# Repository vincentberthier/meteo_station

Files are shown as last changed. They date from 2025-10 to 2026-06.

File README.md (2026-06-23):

# meteo_station

Weather-station firmware in embedded Rust for the ESP32-H2 (ESP32-H2-DevKitM-1),
built on the [Embassy](https://embassy.dev) async runtime over esp-hal + esp-rtos
(`no_std`, `riscv32imac-unknown-none-elf`).

## Workspace layout

- `crates/meteo-firmware` — ESP32-H2 binary: esp-hal/esp-rtos init, GPIO8 status
  LED, Embassy tasks (BMP388 + MLX90614 + BME280 + VEML7700 on a shared I2C bus,
  aggregator, on-chip BLE, RWDT watchdog). esp deps are gated to
  `cfg(target_arch = "riscv32")`.
- `crates/meteo-lib` — hardware-agnostic drivers (host-testable) using
  `embedded-hal-async` traits: BMP388 barometer, MLX90614 IR thermometer, BME280
  humidity sensor, VEML7700 ambient light sensor, and the v2 BLE wire-frame
  (encode/decode + diagnostics byte).
- `crates/meteo-tui` — terminal dashboard (host, `x86_64-linux`): connects to the
  station over BLE, decodes telemetry frames, and renders a live ratatui UI
  (telemetry table + air-temp / sky-temp / pressure charts).

## Build & flash

```bash
just build     # release firmware (riscv32imac)
just flash      # flash to device (espflash, over native USB-Serial-JTAG)
just run        # flash + attach defmt monitor
just clippy     # firmware (riscv) + meteo-lib + meteo-tui (host), -D warnings
just test       # host unit tests (cargo nextest, meteo-lib + meteo-tui)
just format     # cargo fmt
```

See `CLAUDE.md` for the pin allocation, datasheets, and the espflash logging
procedure.

## Live dashboard

`just tui-run` launches the terminal dashboard. It connects to the `MeteoStation`
BLE peripheral and renders live telemetry in the terminal.

```bash
just tui-build                      # build only
just tui-run                        # connect to default address F0:CA:FE:00:00:01
just tui-run -- --address AA:BB:CC:DD:EE:FF   # override station address
```

Press `q`, Esc, or Ctrl-C to quit.

Host prerequisite: `bluetoothd` must be running at runtime; `libdbus-1-dev` is
required at build time (provides the BlueZ D-Bus binding).

## BLE acceptance — `scripts/ble_soak.sh` + `scripts/ble_notify_check.sh`

The ESP32-H2 advertises **on-chip** BLE as `MeteoStation` (static random address
`F0:CA:FE:00:00:01`) and pushes an 18-byte v2 telemetry frame at 1 Hz over a GATT
notify characteristic. The host unit tests only prove the frame codec; two scripts
(run on gaia, BlueZ 5.86) are the real acceptance gate for the radio link:

- **`ble_soak.sh`** — link-stability soak (described below).
- **`ble_notify_check.sh`** — data-flow check: subscribes via BlueZ `AcquireNotify`
  and asserts at least 5 well-formed 18-byte frames (byte[0] == `0x02`) within the
  window. It uses `AcquireNotify` rather than `bluetoothctl notify on` because BlueZ
  only re-emits the `Value` property when it _changes_, and the near-constant
  telemetry would otherwise be deduped to silence.

The script drives, indefinitely:

```
connect → hold HOLD_SECS → disconnect → wait GAP_SECS → reconnect → …
```

polling the link every second via the BlueZ D-Bus `Connected` property. It
prints one `PASS (held 360s)` line per cycle and exits **non-zero** on any
mid-window drop or failed reconnect. A single passing cycle is not acceptance —
the link must hold and repeat over a sustained run.

### Running it

It runs **on gaia** (BlueZ 5.86), which has `bluetoothctl`, `busctl`, and `doas`.
`doas` is needed because the script writes BlueZ connection parameters to
`debugfs` (these reset on every `systemctl restart bluetooth`, so they are
reapplied each run). Deploy and run:

```bash
scp scripts/ble_soak.sh gaia:
ssh gaia ./ble_soak.sh        # Ctrl-C to stop cleanly
```

The script **never starts a scan** — it connects by address off blueman's
standing discovery cache, avoiding a `Discovering: yes` adapter wedge. Ensure
the device is powered and advertising and that blueman discovery is running
before starting.

### Configuration (environment variables)

| Variable | Default | Meaning |
| --- | --- | --- |
| `DEVICE` | `F0:CA:FE:00:00:01` | BLE address of the peripheral |
| `ADAPTER` | `hci0` | Local HCI adapter |
| `HOLD_SECS` | `360` | Seconds the link must stay up per cycle (6 min) |
| `GAP_SECS` | `90` | Seconds between disconnect and reconnect |
| `CONNECT_TIMEOUT` | `30` | Per-step deadline (connect / cache appearance)  |
| `CONN_MIN` | `6` | debugfs `conn_min_interval` (×1.25 ms) |
| `CONN_MAX` | `12` | debugfs `conn_max_interval` (×1.25 ms) |
| `SUPERVISION` | `600` | debugfs `supervision_timeout` (×10 ms = 6 s) |

Example — a shorter hold while iterating:

```bash
HOLD_SECS=60 GAP_SECS=15 ssh gaia ./ble_soak.sh
```

If the link drops, diagnose with `btmon` on gaia during a hold before changing
firmware; the first tuning knobs are the connection-interval / supervision
values, not another code patch.

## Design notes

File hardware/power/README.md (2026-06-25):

# Power subsystem

Solar charging + power path for the weather station, captured as a KiCad 10 schematic.

## Chain

```
PV-12W ─▶ [U6 INA219] ─▶ CN3791 12V MPPT ─▶ 1S LiPo 10Ah ─▶ [U7 INA219] ─▶ MT3608 (5.0V) ─▶ D1 ─▶ DevKit 5V pin
            0x40           (CV term 4.2V)     (buffer + PCM)     0x41
            (harvest)                                            (load + Vbatt)
```

- **Panel:** Seeed PV-12W — Vmp 12 V, Voc 14 V, Isc ~1 A (matches the **12 V** CN3791 variant).
- **Charger:** Hailege CN3791 single-cell MPPT, terminates at 4.2 V. Panel's ~1 A is a
  gentle 0.1C into the 10 Ah cell.
- **Boost:** MT3608 module trimmed to **5.0 V**, feeding the DevKit `5V` pin (J1/14).
- **Isolation diode (D1, 1N5817):** the MT3608 5 V feeds the DevKit 5V pin through D1
  (~0.45 V drop, LDO still has headroom). When you flash over USB, VBUS appears on the 5V
  pin internally (~5 V) and wins; D1 blocks any back-feed into the boost. USB is the
  DevKit's own port, so no second diode is needed.
- **Current/power telemetry (2× INA219, I²C):** two INA219 breakouts (DEWOTHV / INA219B,
  on-board 0.1 Ω 1 % shunt, ±3.2 A) on the shared I2C0 bus, VCC on 3V3.
  - **U6 @ 0x40** — high-side on the PV feed (`SOLAR+ → SOLAR_CHG`): solar **harvest
    current** + panel voltage (bus input rated to 26 V, fine for the ~12–14 V panel).
  - **U7 @ 0x41** — high-side on the battery→boost feed (`VBAT → VLOAD`): **load current**
    drawn by the system + **battery voltage** (the INA219 bus register, more accurate than
    the SAR ADC). Addresses set by the A0 solder jumper.
- **Battery sense:** the GPIO2 / ADC1_CH1 divider is **gone** — battery voltage now comes
  from U7's bus reading. GPIO2 is freed as a spare ADC.
- **I²C pull-ups:** R3/R4 = 4.75 kΩ on SDA/SCL (now six devices on the bus).
- **Decoupling:** C1 (22 µF) at the MT3608 input on `VLOAD` (right at boost VIN, after the
  U7 shunt), C2/C3 (100 µF + 10 µF) on the 5 V rail, C4–C6 on 3V3 (10 µF bulk + 100 nF per
  sensor) — sized to ride out the BLE radio's TX current bursts.

All parts are on hand (see the project Mouser order); the two INA219 modules arrived
2026-06-21 (lot of 2). Current/power telemetry is now populated on the sheet.

## Files

| File | What |
| --- | --- |
| `meteo_power.kicad_sch` | The schematic (KiCad 10, ERC-clean). |
| `meteo_power.kicad_pro` | Project file. |
| `meteo_power.pdf` / `.svg` | Rendered exports. |
| `gen_power_sch.py` | Generator that produces the `.kicad_sch`. |

The schematic is **generated**, not hand-drawn: `gen_power_sch.py` reuses the system KiCad
symbol libraries and wires nets with on-sheet labels (no point-to-point routing). Edit the
`COMPS` / net map in the script and regenerate rather than editing the `.kicad_sch` by hand
— but the `.kicad_sch` is committed so it opens without regenerating.

## Regenerate

```bash
just power-sch        # regenerate sch + ERC + PDF/SVG
```

Needs `kicad-cli` and the KiCad symbol libraries under `/usr/share/kicad/symbols`. The
generator also takes an explicit output directory: `python3 gen_power_sch.py <outdir>`.

## Layout note

Modules (panel, CN3791, MT3608, DevKit, sensors) appear as connector symbols; only the
discretes (R/C/D) are real placed parts. This is a system-interconnect schematic, not a
board — there is no PCB. A soldered carrier board is a possible later step.

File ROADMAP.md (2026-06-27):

# Roadmap — future ideas

The firmware and the bench prototype are at a good **v1**. This file collects ideas
for a future **v2** (mostly mechanical / hardware enclosure work). Nothing here is
committed or scheduled — these are notes to revisit, not a backlog.

**Target deployment: outdoors at ~1500 m in the Alps.** Hard freezing, snow, rime ice,
and large day/night temperature swings are design drivers throughout — see
[Cold-climate operation](#cold-climate-operation-alps-1500-m).

## Enclosure & mechanical

### Proper box

Move off the bench into a real weatherproof enclosure. This is the umbrella task that
several items below feed into (sensor placement, waterproofing, PCB mounting).

### MLX90614 sky-IR protection

The MLX90614 must point straight up at the sky to detect clouds, so its FOV cannot be
shaded or covered in normal operation. But an upward-facing can collects rain and snow,
which then sits in front of the optics and ruins readings.

Options under consideration:

- **Flap** — simple, but a flat flap doesn't drain; water/snow pools on it.
- **Servo** — park the sensor (tilt/rotate away, or under a small shelter) when
  precipitation is detected, point back at zenith otherwise. Better drainage behaviour,
  but more mechanical design work to integrate cleanly into the box. Could trigger off
  the rain-gauge tip events that the firmware already counts.

No decision yet; the servo path is the leading idea but the box geometry has to support it.

### VEML7700 luminosity placement

The ambient-light sensor **cannot** sit inside the box or in shade — it needs an open
view of the sky to read luminosity. Mounting it on top exposes it to weather, so it
needs its own small waterproof (étanche) window/dome. Placement and sealing are an open
design question and interact with the box and the MLX mount.

### Air-temperature radiation shield

The air-temp sensors (BMP388 / BME280) must read true ambient air, not a sun-baked box.
Direct sun on the enclosure will bias the temperature high by several °C and also throws
off the MLX90614 ambient reference. A louvered radiation shield (Stevenson-screen style)
with airflow around the sensor is the standard fix, and it interacts with where the box,
the VEML window, and the MLX mount all sit. Not optional for credible temperature data.

## Electronics

### Stronger BLE radio / antenna

The on-chip ESP32-H2 radio with the DevKitM PCB antenna is weak in practice: **~-80 dBm
at ~5 m** to a phone. That's marginal for a node that may sit at the bottom of the garden
behind walls. Look at a module/board with a proper external antenna (u.FL + whip, or a
PCB-trace antenna with better gain), or a board variant that breaks out the RF for an
external antenna. Goal: solid link at the real deployment distance, not bench distance.

**Check config first — we're at 0 dBm.** Before buying anything: the firmware currently
advertises at **TX power 0 dBm** (it uses `AdvertisementParameters::default()` everywhere,
whose default `tx_power` is `TxPower::ZerodBm`; see `crates/meteo-firmware/src/ble.rs` and
`third_party/trouble-host/src/advertise.rs`). The `TxPower` enum goes up to `Plus20dBm`,
and the ESP32-H2 can transmit well above 0 dBm — so there's ~10–20 dB of link budget
available for free. Raise `tx_power` (mind ETSI EN 300 328: ~+10 dBm is safe without
adaptivity) and re-measure RSSI before concluding the radio/antenna is the bottleneck.
Coded-PHY (long-range) is another no-hardware lever, but central-side support varies.

**Hard constraint: stay in the same family.** If, after maxing TX power, range is still
short, any replacement must be an Espressif / esp-rs part (e.g. an ESP32-C6/C3/S3/H2
variant with a better antenna), so the existing firmware stack (esp-hal / esp-rtos /
esp-radio / trouble-host) ports over with minimal changes. No going back to a separate
external BLE module (the old RN4871 over UART was far too poor and would mean
reprogramming everything) and no other-vendor radio that forces a rewrite.

### Federated multi-board architecture (power + main + tracker + heaters)

Split into separate boards, each with its own power domain, in a hub-and-spoke layout —
the power board is the trunk feeding the other three; the logic boards talk over a
separate comms link:

1. **Power / PMU (trunk).** PV input, MPPT charger (CN3791), battery, cold-charge inhibit
   - over-discharge protection, and all regulated rails (3.3 V logic, 5–6 V servo,
     switched heater rail). Distributes power to the other three. The INA219 current
     monitors live here — with three consumers, prefer **per-domain shunts** (main /
     tracker / heaters) over one lumped reading, so the winter energy balance is legible.
2. **Main.** The current weather station (sensors + BLE), unchanged.
3. **Solar tracker.** 2 servos + 4 LDRs; runs the sun-seek loop locally.
4. **Heaters.** Heating elements; closes a thermostat loop on a local NTC.

**Why split:**

- **Power-domain & EMC isolation** (the real win). Heater amps and inductive servo
  switching stay off the sensitive sensor/analog/RF board — they'd otherwise inject noise
  into the INA219 sensing, the vane/LDR ADC, and the BLE radio.
- **Fault isolation.** A hung tracker or a shorted heater MOSFET doesn't stop core
  telemetry from broadcasting.
- **Independent build/test** per board. Resolves the earlier "separate MCU for the
  tracker?" question — yes, and the same logic gives the heaters their own controller.

**Battery safety stays in hardware.** The power board's cold-charge inhibit and
over-discharge cutoff must be hardware-latched / autonomous, **not** dependent on a
firmware MCU that could hang — a single software fault must not be able to cook or
over-discharge the pack. (The cold-charge and over-discharge items above live on this
board.)

**Keep the satellites autonomous — the main board sends only high-level _mode_, never
real-time control:**

- **→ Heaters:** a single "cold AND precip → enable" latch — the main board already has
  both inputs (BME280 air temp + rain-gauge tips), so it computes the gate itself and
  raises one SR-latch flag; the heater board just acts on it (see below).
- **→ Tracker:** a small command set — `TRACK / LOCK / RESET` (park morning-ready) /
  `STOW` (safety). The tracker runs its own LDR seek loop between commands.

**Signalling = latched hardware flags, not a live bus poll.** Because the satellites
mostly sleep, carry each command as a **hardware SR latch** (set-reset flip-flop) on the
always-on µA rail: the main board **pulses SET**, the latch holds the state with both MCUs
asleep, and the satellite **reads it on wake then pulses RESET** (clear) once it has acted
— a hardware semaphore that "remembers" until cleared. A single `74LVC1G74`-class part per
flag, or an octal latch (`74xx573`) to hold several command bits in one chip. Firmware
side, let the satellite **deep-sleep and wake on the latch line's edge** (ESP32
`ext0/ext1` GPIO wake) rather than polling on a timer — near-zero idle draw. If a flag
must survive a full power-down (not just sleep), use a **latching/bistable relay** or an
FRAM/EEPROM bit instead.

**Heater board needs no MCU — `enable-latch → MOSFET → PTC element`.** Preferred design:
**self-regulating PTC heating elements**. A PTC pulls lots of power when cold, then its
resistance climbs steeply near its Curie temp and it tapers off as it (and its
surroundings) warm — so it regulates itself with no control loop, and a **better-protected
sensor sits warmer → the same PTC self-throttles and draws less**, matching power to local
demand automatically. It's also **intrinsically fail-safe** (can't thermally run away — no
fire path in an unattended box). Caveats: it regulates a _surface_ temperature, not a
precise sensor setpoint (coarse, but fine for frost/snow), and a cold PTC has an **inrush
spike** at switch-on (low resistance until it self-heats) — size the MOSFET + power stage
for it (the per-domain INA219 will show it).

The thermal regulation is therefore the PTC's job; _when to power it at all_ is the main
board's "cold AND precip" enable latch (above). So a separate cold-switch isn't needed for
control — but a **bimetallic snap thermostat** (e.g. KSD9700, normally-closed sub-zero
variant, snap hysteresis) in series is worth keeping as an **independent hardware
backstop**: a physical guarantee the element can't heat above freezing even if the enable
flag sticks on, so a firmware bug can't trickle-drain the battery in summer.

**Fail-safe defaults** (each satellite, on link loss or its own watchdog firing):

- **Tracker → STOW** (never hunt blind); **Heaters → OFF** (no fire, no battery drain).
- Each board carries its own watchdog so a hang can't leave servos energised or a heater
  stuck on.

**Panel safety positions:**

- **Night:** the tracker self-detects darkness (all four LDRs low) and parks east / locked
  — don't hunt on moonlight or a streetlight; the main board's `LOCK` is a backstop.
- **Hail / storm:** stow to a protective angle (edge-on, minimal exposed area). The open
  question is the _trigger_ — hail is hard to sense directly; tie `STOW` to high wind (the
  anemometer) and/or storm conditions, or add a piezo impact sensor for true detection.
  High wind should stow regardless.

**Inter-board link.** Low-rate, but in a heater/servo-noisy outdoor system pick a robust
bus: **CAN** (the H2 has a TWAI controller — differential, multi-drop, noise-immune) is
the industrial-correct choice; isolated GPIO/UART is the simpler path. Consider digital
isolators / optocouplers so satellite noise doesn't flow back into the sensor/RF board.

**Rails & conversion — distribute one bus, regulate at each board.** Don't ship multiple
regulated rails across cables: distribute a **single bus** (the battery, or one
intermediate rail) + the comms/latch signals, and let each board do **point-of-load
regulation** for its own 3.3 V (3.3 V is too drop/noise-sensitive to run between boards),
with the servo 5–6 V generated on the tracker board. Connectors then carry only the bus +
signals, keeping their current rating simple.

**Decision: go to a ~12 V pack and buck everything down** (was an A/B choice; settled
because there is no existing heater to preserve and the battery is being replaced anyway,
so nothing ties the design to 1S). The current 1S (~3.7 V) pack makes 12 V a big _step-up_
boost — a 12 V × 2 A heater ≈ 24 W would pull **7–13 A from a single cell**, beyond many
cells' continuous rating and into a sag→more-current spiral. Raising the battery flips
every rail to a **step-DOWN buck** (efficient, simple, cool), cuts distribution current to
~⅓ (thin wires, small connectors), and sits closer to the panel voltage so the charge path
converts less.

- **Pack:** **4S LiFePO4 (~12.8 V nominal)** with an integrated **BMS** — the right
  chemistry for an unattended cold box (safe, no thermal-runaway fire path, long cycle
  life, better cold _discharge_), and the BMS gives over-discharge protection + cell
  balancing for free (see [over-discharge protection](#battery-over-discharge-protection)).
- **Charger:** a 12 V/4S MPPT solar charge controller replaces the CN3791; the panel Voc
  must clear the ~14.6 V charge voltage with margin (a ~12 V-class panel is fine).
- **Rails:** point-of-load bucks per board — 12→3.3 V (logic), 12→5–6 V (servos), heater
  rail direct off the pack or its own buck.
- **Still required:** the cold-charge inhibit (no lithium charges sub-zero, LiFePO4
  included) stays.
- **Firmware:** drop the 1S-LiPo SoC curve. LiFePO4's discharge curve is very flat, so
  voltage-based SoC is poor — **coulomb-count via the battery-domain INA219** instead
  (the per-domain sensing pays off twice).

**Connectors / board-to-board ports.** Segment by role; don't use one type for everything,
and split power from signal on each run (EMC + independent current rating). High-current
trunk (PV / battery / charge): **XT30/XT60** or **Anderson Powerpole**. Per-board power
feed: a keyed, positive-latch 2-pin (**Molex Micro-Fit 3.0** if a crimp tool is on hand).
Per-board signal (bus + latch lines): a small keyed, latching multi-pin (Micro-Fit / JST-GH
/ small terminal block). **Recommended default given a minimal bench:** pluggable
screw/spring **terminal blocks** (Phoenix COMBICON-style) — keyed, locking, **no crimp
tool**, field-rewireable with a screwdriver; use a **different pin count per port** so a
cable can't be cross-plugged. Non-negotiables: **keying/polarization** (a reversed power
feed fries a board; don't trust wire colour), **positive latch** (wind + thermal cycling
back out friction connectors), **current-rate per port** (heater port worst case),
strain-relief + label every cable. Avoid bare unlatched JST for a winter deployment, fixed
screw terminals where you want clean disconnects, and Dupont/breadboard jumpers entirely.

### Proper PCB

Replace the breadboard/jumper wiring with a designed PCB. Cleaner, more robust, and a
prerequisite for a real deployable unit.

**Use the certified module, not the bare chip.** Lay down an `ESP32-H2-MINI-1` (or
`-C6-MINI-1`) castellated module — chip + flash + crystal + RF frontend + antenna + CE/FCC
cert in one SMD part. The bare QFN means designing the RF match, crystal, antenna tuning,
and re-certifying — not worth it. Drop the devkit extras (USB-JTAG bridge, AMS1117,
buttons, headers); add back only a USB connector + boot/reset strapping (flashing is over
native USB-Serial-JTAG) and an on-board 3.3 V regulator — ideally the buck-boost from the
power phase-2 note, killing the double conversion.

**What forces component changes (design the board around these):**

- **BLE/MCU variant — decide first; it is the board's centre.** A different ESP variant
  also means re-validating the BLE stack (the vendored supervision-timeout patch is
  H2-controller-specific; a C6 may behave differently, possibly not needing it).
- **Servos** (MLX rain-park + solar tracker) — PWM pins + power-switching MOSFETs + a
  **5–6 V servo rail** (not the 3.3 V logic rail).
- **Tracker's 4 photoresistors** — 4 ADC inputs; watch the pin/ADC budget (the wind vane
  already uses one ADC channel).
- **Heaters** — MOSFET drivers + a heater rail straight off battery/12 V + NTCs for
  thermostatic control. Size the power stage for this worst-case current.
- **Battery cold-charge / over-discharge protection** — NTC + charge-inhibit, a protection
  IC / protected cell, or a charger with a temp pin.
- **RTC + SD** (on-device logging) — RTC chip + backup coin cell + SD socket; optional if
  the Pi collector owns the history.

**No component change:** all current sensors (BMP/BME/MLX/VEML/INA/weather-meter), the web
server and Android app (off-board), deep-sleep (firmware), and the box / radiation shield /
VEML mounting (mechanical). Battery and solar don't change _type_ — but heaters + the
winter worst case could force a bigger panel/battery _size_ (a measurement call, see
[Power & energy](#power--energy)).

**Future-proof the layout.** A respin costs weeks; break out **unpopulated (DNP) footprints
and headers** for the deferred loads — servo header + MOSFET pads, a spare-ADC breakout for
the LDRs, heater-driver footprints, an NTC pad, I²C pads for an RTC, SD pads — and spec the
power stage for the heater worst case even if unpopulated. Then each v2 feature is a
soldering job, not a new board.

### 2-axis solar tracker

Add a 2-axis tracking mount for the PV panel, using **4 photoresistors** that orient the
panel by balancing the shade/light across the four quadrants (classic LDR-bridge tracker).

- Runs on its own board with its own MCU — see
  [Federated multi-board architecture](#federated-multi-board-architecture-power--main--tracker--heaters).
  The standalone controller keeps the servo PWM and the sun-seek loop (and night/stow
  safety) off the weather firmware, and the main board commands it only by mode
  (`TRACK / LOCK / RESET / STOW`).
- **Hybrid duty cycle.** Active by day — timer-paced ~1 min wakes to re-aim — but
  **deep-sleep at night / when stowed**, waking only on a latch-line edge (`RESET`/`STOW`
  from main) for near-zero idle draw. Entering night sleep is gated by the LDRs going dark
  (or the `LOCK`/`STOW` flag). The setter (main) never sleeps — it runs the BLE radio
  continuously — so the latch line is always actively driven; no RTC-GPIO hold needed on
  the main side.
- Single-axis reference design:
  <https://www.sciencebuddies.org/science-fair-projects/project-ideas/Energy_p045/energy-power/solar-tracker>

## Power & energy

### Energy-budget analysis before resizing

Concern: stronger BLE TX + a 2-axis tracker may need a bigger battery/panel. Settle it by
**measurement, not guesswork** — the INA219s already log `solar_mv/ma`, `batt_mv`,
`load_ma`, so capture the real balance over several days (ideally across a low-sun spell)
before buying anything. Earlier analysis had the 12 W panel massively over-supplying the
node, so there is real headroom. Notes on the two additions:

- **BLE TX bump is negligible.** TX is brief bursts at 1 Hz advertising; 0 → +10 dBm
  raises peak TX current but barely moves the average. Not a battery-sizing driver.
- **The tracker is the real consumer — but it's net-positive if designed right.** A
  2-axis tracker harvests roughly +30–40% over a fixed panel. Keep servo energy well
  under that gain: **power-gate the servos** (MOSFET, off between moves), adjust only
  every few minutes (the sun moves ~15°/h), and avoid holding position under power
  (worm gear / detent, or tolerate small drift). Then it funds its own draw and then
  some, especially mornings/evenings/winter.
- A bigger battery is cheap insurance for low-sun spells regardless — but make it a
  measured call, not a pre-emptive guess.

### Deep-sleep / duty-cycling

The firmware currently runs continuously and advertises at 1 Hz. Duty-cycling the sensors
and radio (sample + broadcast a burst, then sleep) is the biggest lever for average draw —
potentially removing the need for a bigger battery at all. Tension: continuous 1 Hz
broadcast is what makes the passive-scan dashboards work, so a battery profile would trade
freshness for endurance (e.g. broadcast a burst every N seconds, sleep between). Pairs
naturally with the buck-boost efficiency upgrade already noted in the power phase-2 work.

### Battery over-discharge protection

Any lithium pack run flat is damaged or dangerous. The chosen **4S LiFePO4 with integrated
BMS** (see [Rails & conversion](#rails--conversion-distribute-one-bus-regulate-at-each-board))
covers the low-voltage cutoff and balancing in hardware; still add a firmware low-battery
state that sheds load (drop servo moves, slow the broadcast) before the BMS cutoff trips.
The `batt_mv` telemetry gives the early-warning signal. See also cold-charge protection
under Cold-climate operation below.

## Cold-climate operation (Alps, ~1500 m)

The station lives outdoors at altitude: hard freezing, snow, rime ice, condensation, and
big temperature swings. This is a cross-cutting constraint, not a single feature.

### Battery cold-charge protection (critical)

No lithium chemistry — the chosen **4S LiFePO4** included — **may be charged below 0 °C**:
charging a frozen cell plates lithium, permanently damages it, and is a fire risk. At
1500 m in winter the pack will be sub-zero exactly when the sun appears to charge it, so
this must be solved regardless of sensors:

- An **NTC thermistor on the pack** driving a **charge-inhibit below ~0–5 °C** (gate the
  charge path, or use a 12 V/4S MPPT charger that exposes a temp/NTC pin).
- And/or insulate + gently warm the battery compartment up to a safe charge temperature
  before enabling charge.
- LiFePO4 tolerates cold _discharge_ better than LiPo — but, as above, it still can't be
  charged sub-zero, so the inhibit is needed either way.
- Discharge is fine down to roughly -20 °C, just at reduced capacity; insulation helps
  hold the pack warmer than ambient.
- **The pack is getting replaced for the cold anyway, so size it once for the winter
  worst case _with_ heaters** — the marginal cost of a bigger cell now beats a second swap
  later. But note the cold-charge inhibit is **required regardless of chemistry**: LiFePO4
  tolerates cold _discharge_ better, yet still can't be charged sub-zero, so swapping
  chemistry does not remove this requirement.

### Sensor heaters

Heating to keep sensors reading truthfully through frost and snow. Ranked by whether the
watts are worth it:

- **Rain gauge** — a tipping bucket can't measure snow; it only registers later when the
  snow melts, so timing and rate are wrong. A heated funnel melts it on contact. This is
  the **biggest power draw** (several watts) and the main budget problem.
- **Anemometer + wind vane** — rime ice seizes the moving parts and reports false calm.
  Heating moving parts/bearings is hard; at minimum, **detect a stuck rotor and flag it**
  (diagnostics bit) rather than broadcasting 0 km/h as truth.
- **MLX90614 / VEML7700 windows** — frost and condensation block the optics. Small
  anti-frost window heaters, or for the MLX the servo-park already planned under
  "MLX90614 sky-IR protection".
- **Enclosure condensation** — breather vent + desiccant, possibly a trickle heater, to
  stop temp swings from fogging/icing the inside.

### The power-budget collision

Heaters are by far the largest loads, and they peak exactly when solar is weakest: short
winter days, low sun angle, snow on the panel. Continuous rain-gauge heating may not be
sustainable on the current solar budget. Honest options, to decide per sensor:

- **Thermostatic / demand-driven** heating — energise only when near-freezing **and**
  precipitation is detected (the temp + rain-gauge telemetry already exist to gate it);
  PTC self-regulating elements simplify the control.
- A materially **bigger panel + battery** sized for the winter worst case.
- Accept **degraded snow/ice measurement** in deep winter as a deliberate tradeoff.

This interacts directly with [Power & energy](#power--energy) — size the winter budget
from measured data before committing to heaters.

## Software

### Android app

A phone app would be a nice front-end alongside the `meteo-tui` dashboard: passively scan
for the `MeteoStation` advert, decode the same manufacturer-data telemetry frame
(company `0xFFFF`, the v5 wire format in `meteo-lib::ble::frame`), and show live readings +
history. No GATT connection needed for telemetry; the PIN-gated location write could be a
nice-to-have config screen. A stronger BLE radio (above) would help the app's link too.

### Over-the-air (OTA) firmware update

Update the firmware without physically reaching the station. Feasible, no blockers, but a
meaningful project.

- **BLE-only path.** The ESP32-H2 has no Wi-Fi (802.15.4 + BLE), so OTA must go over the
  existing BLE link — not the usual Wi-Fi/HTTP OTA.
- **Reuses what's already here.** Partition-table reads via `esp-bootloader-esp-idf`,
  flash writes from the config task (`sequential-storage`), and the PIN-gated GATT write
  channel are all patterns the firmware already uses.
- **New work:** an OTA partition layout (`ota_0` / `ota_1` / `otadata` instead of the
  single app partition; check the image fits twice in flash), a DFU GATT service that
  receives the image in chunks → writes the inactive slot → flips `otadata` → resets,
  rollback-on-failure safety, and a host-side uploader tool.
- **Throughput caveat.** BLE moves an image slowly (low tens of KB/s even with a larger
  MTU / 2M PHY / data-length extension) — minutes per update for a few-hundred-KB image.
  Fine for occasional field updates; OTA complements the USB-JTAG flash path, it doesn't
  replace it for day-to-day iteration. A stronger BLE link (see above) would also speed
  this up.

### Programming & updating all the boards

The OTA item above covers the Main board; with the
[multi-board architecture](#federated-multi-board-architecture-power--main--tracker--heaters)
the whole fleet needs a flashing/update story. How it stays manageable:

- **Fewer programmable boards is the first win.** The heaters and power/PMU boards are
  designed MCU-less (PTC + latches; hardware-latched battery safety), so they have **no
  firmware** and drop out of the update problem. Only **Main + Tracker** are programmable,
  and only Main has a radio.
- **A wired programming path on every programmable board, always.** Each carries a
  programming/debug header or USB-Serial-JTAG pads — for bring-up _and_ as the recovery
  path when an OTA bricks. Never seal a board you can't physically re-flash.
- **Main is the field update gateway.** An image arrives over BLE to Main (the OTA item
  above), and Main **forwards firmware to the Tracker over the inter-board bus** (CAN/UART)
  into a bootloader on the Tracker that writes its own flash — same A/B + rollback pattern
  as Main's OTA, with the bus as transport instead of BLE. One BLE push (or the Pi) updates
  the sealed box. The bus must carry bulk payloads, not just command flags (CAN needs
  ISO-TP and is slow-ish; UART is faster — minutes per image either way).
- **Same MCU family across satellites** (extends the BLE "stay in the family" rule): one
  toolchain, one bootloader protocol, one update mechanism, shared `meteo-lib`.
  Heterogeneous MCUs would mean parallel toolchains and update paths.
- **Version the fleet.** Each board reports its firmware version (Main in telemetry,
  Tracker over the bus), and the **inter-board protocol is versioned** so a freshly-updated
  Main doesn't issue a command a stale Tracker can't parse. A/B + rollback per board; a
  Tracker that bricks mid-update must fall to its `STOW` fail-safe and stay re-flashable.
  Main is the most critical — if Main bricks, the gateway to everyone is lost, so its
  rollback + wired recovery matter most.
- **The Pi collector, if built, is the natural local update host** — it already talks to
  the station, so it can serve firmware over BLE (or a wired link when co-located).

### Web server for historic data (Raspberry Pi collector) — IMPLEMENTED (`meteo-web`)

**Status: implemented as `crates/meteo-web`.** The `meteo-web` crate is a Leptos 0.8 SSR
application (cargo-leptos) that runs the BLE collector and the web server in one binary.
See `CLAUDE.md §"Web dashboard (meteo-web / meteo-chart)"` for the full architecture.

What was built matches the original design notes:

- Passive BLE scan (bluer) reusing `meteo-lib::ble::frame::decode` — same wire format as
  `meteo-tui`, no re-implementation.
- 1-minute min/max/avg SQLite buckets (`samples` table, WAL, `~170 KiB/day`).
- Query-time re-aggregation (`GROUP BY bucket_ts / bucket_secs`) with
  sample-count-weighted averages; no rollup tables needed.
- Two web pages: `/` (all-panels live + history grid) and `/comparaison` (multi-day
  overlay chart). Custom Leptos SVG charts matching the TUI palette and layout.
- Live SSE stream at `GET /live` — 1 Hz `LiveFrame` JSON events.
- Pi deployment path: `just web-build-pi` (aarch64 cross-build; needs toolchain installed
  — see `CLAUDE.md`).
- Timestamps from NTP wall-clock (the Pi has it), making on-device RTC optional for
  history.

Remaining open item from the original note: the Pi cross-build toolchain (`aarch64-
unknown-linux-gnu` rustup target + cross linker) is not yet installed; `just web-build-pi`
will fail until it is. `just web-build` and `just web-serve` work on the dev host today.

### On-device logging & RTC

Today telemetry is broadcast live only — if no observer is scanning, that data is gone.
On-device storage (a ring buffer in flash, or an SD card for real capacity) would keep a
continuous record the dashboard/app can backfill from on next contact. This needs real
timestamps, so pair it with a battery-backed RTC (e.g. DS3231 on the existing I2C0 bus) —
the H2 has no network time and loses its clock on power loss. The frame already carries
`uptime_s`, but that resets every reboot; wall-clock time makes logs comparable.

## References

- Example weather station (Printables) — **for ideas only, not to copy**:
  <https://www.printables.com/model/61709-weather-station-one-part-1-the-central-station>

## Related notes

- Power-subsystem phase-2 upgrades (buck-boost to 3.3V for efficiency; the INA219
  current monitoring from that note is now built) are tracked separately.
- See `CLAUDE.md` for the firmware-side follow-ups (WS2812 colour LED, upstreaming the
  vendored trouble-host patch).

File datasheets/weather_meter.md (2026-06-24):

# SparkFun Weather Meter Kit (SEN-15901)

**Manufacturer:** Shenzhen Fine Offset Electronics

## Overview

Three passive sensors using sealed magnetic reed switches -- no active electronics.

1. **Cup anemometer** (wind speed)
2. **Wind vane** (direction)
3. **Tipping bucket rain gauge**

---

## Wind Speed Sensor (Anemometer)

- **Interface:** Reed switch (contact closure), count pulses via GPIO interrupt
- **Calibration:** 1 Hz = 2.4 km/h

```
wind_speed_kmh = pulses_per_second * 2.4
wind_speed_ms  = pulses_per_second * 0.667
```

- External pull-up required (or MCU internal)
- **Debounce:** ~10-15 ms (hardware RC or software)
- Max frequency at extreme wind: ~67 Hz

---

## Wind Direction Sensor (Wind Vane)

- **Interface:** Analog (resistive), read via voltage divider + ADC
- 8 reed switches with different resistors, magnet can close 1-2 adjacent -> **16 positions** (22.5 degree steps)

### Resistance Table

| Direction | Degrees | Resistance (ohm) |
| --- | --- | --- |
| N | 0 | 33,000 |
| NNE | 22.5 | 6,570 |
| NE | 45 | 8,200 |
| ENE | 67.5 | 891 |
| E | 90 | 1,000 |
| ESE | 112.5 | 688 |
| SE | 135 | 2,200 |
| SSE | 157.5 | 1,410 |
| S | 180 | 3,900 |
| SSW | 202.5 | 3,140 |
| SW | 225 | 16,000 |
| WSW | 247.5 | 14,120 |
| W | 270 | 120,000 |
| WNW | 292.5 | 42,120 |
| NW | 315 | 64,900 |
| NNW | 337.5 | 21,880 |

### ADC Voltage Formula

With external pull-up R_pullup to VCC:

```
V_out = VCC * R_vane / (R_vane + R_pullup)
```

Use 10k pull-up. Match ADC reading against lookup table with +/-2% tolerance.

---

## Rain Gauge

- **Interface:** Reed switch (contact closure), GPIO interrupt
- **Calibration:** 1 tip = 0.2794 mm rain

```
rainfall_mm = tip_count * 0.2794
```

- Recommended debounce: **100-200 ms** (mechanical tipping is slow)
- Reference circuit: 100k pull-up, 10 pF debounce cap

---

## Connectors (RJ-11)

**This unit ships three separate RJ-11 cables — one per sensor.** (Some SparkFun
SEN-15901 revisions combine the wind vane + anemometer onto a single shared cable;
this one does not. Verified against the physical kit, 2026-06.) Each sensor is a
2-terminal passive device on its own jack:

| Cable | Sensor function | Notes |
| --- | --- | --- |
| Anemometer | reed switch (2 wires) | non-polar contact closure |
| Rain gauge | reed switch (2 wires) | non-polar contact closure |
| Wind vane  | resistive (2 wires) | resistance-to-common, non-polar |

**Which two of the (up to 6) conductors in each RJ-11 are the live pair varies by
cable batch — confirm with a multimeter before wiring.** Continuity mode:
spin the cups (anemometer pair beeps intermittently), tip the bucket (rain-gauge
pair beeps), rotate the vane (pair reads a changing resistance per the table
above). Ignore any open/unused conductors.

**Breakout:** use an RJ-11 6P6C breakout board (jack → labelled 0.1″ header pins
1–6) per sensor — plug in, meter the live pair, jumper to the MCU. A 6P6C jack
seats 6P4C/6P2C plugs fine; the extra pins stay dead.

**Confirmed live pairs for THIS kit (bench-verified 2026-06):**

| Cable | Live pair on its 6P6C breakout | Plug type |
| --- | --- | --- |
| Anemometer | **middle pair, pins 3 & 4** | 6P2C (seated centred) |
| Rain gauge | **middle pair, pins 3 & 4** | 6P2C (seated centred) |
| Wind vane  | **pins 2 & 5** | wider plug |

Each cable is an independent crimp, so a pair's position on one breakout does **not**
predict another's — confirm each. (An earlier "outer pair = rain by deduction" guess
was wrong: the rain gauge is a 6P2C like the anemometer, so its live pair is the
**middle**, not the sides, and the outer pins are dead.) When a multimeter isn't
handy, `crates/meteo-firmware/src/bin/probe.rs` (`just probe`) identifies the live
pair hands-free over defmt.

---

## STM32H753ZI Integration Notes

- **Anemometer + rain gauge:** two GPIO pins as external interrupts (falling edge) with pull-ups
- **Wind vane:** one ADC channel, recompute voltage table for 3.3V supply
- All sensors passive, compatible with 3.3V or 5V -- no level shifting needed at 3.3V

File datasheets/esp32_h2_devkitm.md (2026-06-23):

# ESP32-H2-DevKitM-1

**SoC:** Espressif ESP32-H2 (`ESP32-H2-MINI-1` module, QFN32) — candidate
replacement for the STM32H753ZI + RN4871 pair. BLE is **on-chip**, so the whole
external-module path (RN4871 + USART2 + reset GPIO) disappears.

Module variants: **`-N4`** (PCB antenna) and **`-1U-N4`** (external antenna
connector). Both have 4 MB in-package flash, 0 MB PSRAM.

## Chip summary (datasheet v1.2)

| Item | Value |
| --- | --- |
| Core | RISC-V 32-bit single-core @ 96 MHz, 4-stage pipeline |
| Memory | 320 KB SRAM, 128 KB ROM, 16 KB cache, 4 KB LP, 4 MB flash |
| Radio | **Bluetooth 5.3 LE** (Coded PHY long range, 2 Mbps, adv. ext.) + 802.15.4 |
| I2C / UART / SPI | 2× I2C, 2× UART, general-purpose SPI |
| ADC | One 12-bit SAR ADC, **5 channels on GPIO1–GPIO5** (ADC1 only) |
| USB | Native USB-Serial-JTAG (flash + `defmt` log + debug over one USB-C) |
| GPIOs | 19 programmable; **strapping: GPIO8, GPIO9, GPIO25** |
| Deep-sleep | 7 µA (LP memory retained) |
| Toolchain | `riscv32imac-unknown-none-elf`, stock Rust + `espflash` (no Xtensa fork)  |

Reference docs:

- [ESP32-H2 chip datasheet (v1.2)](https://documentation.espressif.com/esp32-h2_datasheet_en.pdf)
- [ESP32-H2-MINI-1/1U module datasheet](https://www.espressif.com/sites/default/files/documentation/esp32-h2-mini-1_mini-1u_datasheet_en.pdf)
- [DevKitM-1 user guide](https://docs.espressif.com/projects/esp-dev-kits/en/latest/esp32h2/esp32-h2-devkitm-1/user_guide.html)
- [DevKitM-1 schematics v1.3](https://dl.espressif.com/dl/schematics/esp32-h2-devkitm-1_v1.3_schematics.pdf)

## Board pinout + weather-station wiring

Two 15-pin headers, `J1` and `J3`. **The big label is the SILKSCREEN printed on
TOP of the board — that's what you read at a glance.** `(n)` is the J#/pin number,
which is printed on the **underside only**. Every pin is listed; nothing is left
blank.

```
   ── J1 header ──────────────────────────────────────────
   SILK   GPIO     connect / role                      (#)
   ────   ──────   ─────────────────────────────────   ───
   3V3      —      → sensor VCC (3.3 V rail)            (1)
   RST      —      ✗ reset button — leave              (2)
   0      GPIO0    · free  (spare digital)             (3)
   1      GPIO1    → WIND VANE         [ADC1_CH0]       (4)
   2      GPIO2    → BATTERY sense     [ADC1_CH1]       (5)
   3      GPIO3    · free  (spare ADC)                  (6)
   13/N   GPIO13   · free  (or 32k XTAL if fitted)      (7)
   14/N   GPIO14   · free  (or 32k XTAL if fitted)      (8)
   4      GPIO4    · free  (spare ADC)                  (9)
   5      GPIO5    · free  (spare ADC)                 (10)
   NC       —      ✗ no connect                        (11)
   VBAT     —      ✗ LiPo supply IN — optional         (12)
   G        —      → ground                            (13)
   5V       —      ✗ 5 V rail                          (14)
   G        —      → ground                            (15)

   ── J3 header ──────────────────────────────────────────
   SILK   GPIO     connect / role                      (#)
   ────   ──────   ─────────────────────────────────   ───
   G        —      → ground                            (1)
   TX     GPIO24   · debug UART TX — optional          (2)
   RX     GPIO23   · debug UART RX — optional          (3)
   10     GPIO10   → I2C SDA                            (4)
   11     GPIO11   → I2C SCL                            (5)
   25     GPIO25   ✗ reserved — strapping, leave open  (6)
   12     GPIO12   → RAIN GAUGE                         (7)
   8      GPIO8    ◆ onboard RGB LED — no wire needed   (8)
   22     GPIO22   → ANEMOMETER                         (9)
   G        —      → ground                            (10)
   9      GPIO9    ✗ reserved — BOOT button            (11)
   G        —      → ground                            (12)
   27     GPIO27   ✗ reserved — native USB D+          (13)
   26     GPIO26   ✗ reserved — native USB D-          (14)
   G        —      → ground                            (15)

   Legend:  → wire to sensor      · free / spare (usable later)
            ✗ reserved / leave open      ◆ onboard (no external wire)
```

### Pin assignment table

| Function | Silk / GPIO | Header / No. | Notes |
| --- | --- | --- | --- |
| I2C SDA | `10` / GPIO10 | J3 / 4 | non-ADC; shared bus for all 4 I2C sensors |
| I2C SCL | `11` / GPIO11 | J3 / 5 | 4.7 kΩ pull-ups to 3V3 |
| Wind vane (analog) | `1` / GPIO1 | J1 / 4 | ADC1_CH0 |
| Battery sense (analog) | `2` / GPIO2 | J1 / 5 | ADC1_CH1 |
| Anemometer (pulse) | `22` / GPIO22 | J3 / 9 | input IRQ, pull-up, ~10–15 ms debounce |
| Rain gauge (pulse) | `12` / GPIO12 | J3 / 7 | input IRQ, pull-up, ~100–200 ms debounce |
| Status LED | `8` / GPIO8 | J3 / 8 (onboard RGB) | addressable RGB; strapping — drive post-boot |
| Sensor power | `3V3` | J1 / 1 | all sensors run at 3.3 V (no level shifting) |
| Ground | `G` | J1/13,15 · J3/1,10,12,15 | |

**Pin budget: 6 signal pins + onboard LED used; GPIO0, GPIO3, GPIO4, GPIO5 (3
spare ADC channels) remain free** — not pin-constrained.

## I2C bus — four sensors, one bus

All addresses distinct, so they coexist on the single GPIO10/GPIO11 bus:

| Sensor | Address | Measures |
| --- | --- | --- |
| VEML7700 | `0x10` | ambient light |
| MLX90614 | `0x5A` | IR (object) temperature  |
| BMP388 | `0x76`/`0x77` | pressure, temperature |
| BME280 | `0x76`/`0x77` | humidity, pressure, temp |

- BMP388 and BME280 share the `0x76`/`0x77` pair — put one at each. You cannot
  place two of the _same_ part on the bus. (BME280 is nearly a BMP388 superset;
  you may not want both.)
- **MLX90614 is SMBus**: it can power up in PWM mode — the driver must issue an
  SMBus request to switch to I2C. Drive any GY-906 breakout at 3.3 V for clean
  levels.

## Weather-meter wiring (SparkFun SEN-15901)

```
Anemometer:   GPIO22 ──┬── reed switch ── GND      (internal pull-up + SW debounce)
Rain gauge:   GPIO12 ──┬── reed switch ── GND      (internal pull-up + SW debounce)

Wind vane:    3V3 ── 10kΩ ──┬── GPIO1 (ADC1_CH0)
                            │
                       vane resistive ── GND        (recompute table for 3.3 V)
```

- Wind vane resistance table and the `V_out = VCC·R_vane/(R_vane+R_pullup)`
  lookup are in `weather_meter.md` — recompute the voltage thresholds for the
  H2's attenuated ~0–3.1 V ADC range.
- The ESP32 SAR ADC is noisier/less linear than the STM32H7's, but has eFuse
  calibration and the vane only needs 16 coarse buckets (±2 %), so it's adequate.

## Battery monitoring (LiPo)

```
LiPo+ ── R1 ──┬── GPIO2 (ADC1_CH1)
              │
              R2 ── GND
```

Size the divider so the max cell voltage (4.2 V) lands under the ADC full-scale
(~3.1 V with 12 dB attenuation). E.g. `R1 = R2 = 100 kΩ` → 2.1 V at 4.2 V.
(`VBAT` on J1/12 is a _power input_ to the chip, not a measurement pin — wire
your own divider.)

## Notes / open items

- **32 kHz crystal:** GPIO13/GPIO14 (J1/7,8) are consumed only if a 32.768 kHz
  crystal is populated, which matters for an accurate RTC (log timestamps).
  Confirm against the v1.3 schematic; if absent, they're two more free GPIOs.
- **Debug logging:** flash and stream `defmt` over the native USB-Serial-JTAG
  port (`espflash`); the J3 TX/RX (U0TXD/U0RXD) UART console is a fallback.
- **GPIO2–GPIO5** carry the JTAG (MTxx) functions but are free here because the
  H2's JTAG runs over USB — usable as ADC/GPIO.

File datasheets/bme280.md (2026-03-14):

# BME280 -- Combined Digital Humidity, Pressure and Temperature Sensor

**Manufacturer:** Bosch Sensortec
**Document:** BST-BME280-DS001-24, Rev 1.24, February 2024
**Package:** 2.5 mm x 2.5 mm x 0.93 mm metal-lid LGA, 8 pins

## Device Overview

The BME280 is a combined digital humidity, pressure, and temperature sensor. It is register- and performance-compatible with the BMP280 digital pressure sensor. Each sensing element can be independently enabled or disabled. Supports both I2C (up to 3.4 MHz) and SPI (up to 10 MHz).

Three power modes:

- **Sleep mode** (default after POR): no measurements, lowest power (0.1 uA typ).
- **Forced mode**: one measurement cycle, then returns to sleep.
- **Normal mode**: perpetual cycling between measurement and standby.

## Pin Descriptions

| Pin | Name  | Description | I2C Connection |
| --- | ----- | --- | --- |
| 1 | GND | Ground | GND |
| 2 | CSB | Chip select | VDDIO (selects I2C) |
| 3 | SDI | Serial data | SDA |
| 4 | SCK | Serial clock | SCL |
| 5 | SDO | Address select | GND (0x76) or VDDIO (0x77) |
| 6 | VDDIO | Digital supply | VDDIO |
| 7 | GND | Ground | GND |
| 8 | VDD | Analog supply  | VDD |

## Electrical Characteristics

### Power Supply

| Parameter | Min  | Typ | Max | Unit |
| --- | ---- | --- | --- | ---- |
| VDD | 1.71 | 1.8 | 3.6 | V |
| VDDIO | 1.2  | 1.8 | 3.6 | V |

### Current Consumption

| Condition | Typ | Max | Unit |
| --- | --- | --- | ---- |
| Sleep mode | 0.1 | 0.3 | uA |
| 1 Hz forced, H+T | 1.8 | 2.8 | uA |
| 1 Hz forced, P+T | 2.8 | 4.2 | uA |
| 1 Hz forced, H+P+T | 3.6 | --  | uA |

### Startup Time: 2 ms max

## I2C Details

### Addresses

- **SDO = GND**: `0x76`
- **SDO = VDDIO**: `0x77`

Supports Standard, Fast, and High Speed modes. No clock stretching. Recommended pull-ups: 4.7 kOhm.

### Protocol

- **Write:** address pairs NOT auto-incremented. Send (register, data) pairs.
- **Read:** set register address in write mode, then repeated-start in read mode. Auto-increments. **Burst reads strongly recommended** for data consistency.

## Register Map

### Control and Status

| Address | Name | Default | Description |
| --- | --- | --- | --- |
| 0xD0 | id | 0x60 | Chip ID (always 0x60) |
| 0xE0 | reset | 0x00 | Write 0xB6 for full POR |
| 0xF2 | ctrl_hum  | 0x00 | Humidity oversampling. **Changes take effect after write to ctrl_meas.** |
| 0xF3 | status | 0x00 | bit3: measuring, bit0: im_update |
| 0xF4 | ctrl_meas | 0x00 | [7:5] osrs_t, [4:2] osrs_p, [1:0] mode |
| 0xF5 | config | 0x00 | [7:5] t_sb, [4:2] filter, [0] spi3w_en. Write in sleep mode. |

### Data Registers

| Address | Name  | Description |
| --- | ----- | --- |
| 0xF7-0xF9 | press | Pressure (20-bit unsigned) |
| 0xFA-0xFC | temp  | Temperature (20-bit unsigned) |
| 0xFD-0xFE | hum | Humidity (16-bit unsigned) |

Burst read 0xF7-0xFE for all three.

### Calibration Data

| Address | Coefficient | Type |
| --- | --- | --- |
| 0x88-0x89 | dig_T1 | unsigned short |
| 0x8A-0x8B | dig_T2 | signed short |
| 0x8C-0x8D | dig_T3 | signed short |
| 0x8E-0x8F | dig_P1 | unsigned short |
| 0x90-0x91 | dig_P2 | signed short |
| 0x92-0x93 | dig_P3 | signed short |
| 0x94-0x95 | dig_P4 | signed short |
| 0x96-0x97 | dig_P5 | signed short |
| 0x98-0x99 | dig_P6 | signed short |
| 0x9A-0x9B | dig_P7 | signed short |
| 0x9C-0x9D | dig_P8 | signed short |
| 0x9E-0x9F | dig_P9 | signed short |
| 0xA1 | dig_H1 | unsigned char |
| 0xE1-0xE2 | dig_H2 | signed short |
| 0xE3 | dig_H3 | unsigned char |
| 0xE4/0xE5[3:0] | dig_H4 | signed short (12-bit packed) |
| 0xE5[7:4]/0xE6 | dig_H5 | signed short (12-bit packed) |
| 0xE7 | dig_H6 | signed char |

## Oversampling Settings

| Value | Oversampling |
| ----- | --- |
| 000 | Skipped |
| 001 | x1 |
| 010 | x2 |
| 011 | x4 |
| 100 | x8 |
| 101+  | x16 |

## Standby Time (config bits [7:5])

| Value | t_standby (ms) |
| ----- | --- |
| 000 | 0.5 |
| 001 | 62.5 |
| 010 | 125 |
| 011 | 250 |
| 100 | 500 |
| 101 | 1000 |
| 110 | 10 |
| 111 | 20 |

## IIR Filter (config bits [4:2])

| Value | Coefficient | Samples to 75% |
| ----- | --- | --- |
| 000 | Off | 1 |
| 001 | 2 | 2 |
| 010 | 4 | 5 |
| 011 | 8 | 11 |
| 100+  | 16 | 22 |

Applies to pressure and temperature only (not humidity).

## Measurement Timing

```
t_measure_typ = 1 + [2 * T_os] + [2 * P_os + 0.5] + [2 * H_os + 0.5]  (ms)
t_measure_max = 1.25 + [2.3 * T_os] + [2.3 * P_os + 0.575] + [2.3 * H_os + 0.575]  (ms)
```

## Sensor Specifications

| Sensor | Range | Accuracy | Resolution |
| --- | --- | --- | --- |
| Humidity | 0-100 %RH | +/-3 %RH (20-80 %RH, 25 C) | 0.008 %RH  |
| Pressure | 300-1100 hPa | +/-1.0 hPa absolute | 0.18 Pa |
| Temperature | -40 to +85 C | +/-0.5 C (0-65 C) | 0.01 C |

## Recommended Settings

| Use Case | Mode | P | T | H | IIR | Current |
| --- | --- | ---- | --- | ---- | --- | --- |
| Weather monitoring | Forced 1/min | x1 | x1  | x1 | off | 0.16 uA |
| Humidity sensing | Forced 1 Hz | skip | x1  | x1 | off | 2.9 uA  |
| Indoor navigation  | Normal t_sb=0.5ms | x16  | x2  | x1 | 16  | 633 uA  |
| Gaming | Normal t_sb=0.5ms | x4 | x1  | skip | 16  | 581 uA  |

## Compensation Algorithms (32-bit Integer)

**Temperature** (returns 0.01 C, e.g. "5123" = 51.23 C):

```c
BME280_S32_t t_fine;  // global, used by pressure and humidity

BME280_S32_t BME280_compensate_T_int32(BME280_S32_t adc_T)
{
    BME280_S32_t var1, var2, T;
    var1 = ((((adc_T>>3) - ((BME280_S32_t)dig_T1<<1))) * ((BME280_S32_t)dig_T2)) >> 11;
    var2 = (((((adc_T>>4) - ((BME280_S32_t)dig_T1)) * ((adc_T>>4) - ((BME280_S32_t)dig_T1)))
        >> 12) * ((BME280_S32_t)dig_T3)) >> 14;
    t_fine = var1 + var2;
    T = (t_fine * 5 + 128) >> 8;
    return T;
}
```

**Pressure** (returns Pa as Q24.8, e.g. "24674867" = 96386.2 Pa):

```c
BME280_U32_t BME280_compensate_P_int64(BME280_S32_t adc_P)
{
    BME280_S64_t var1, var2, p;
    var1 = ((BME280_S64_t)t_fine) - 128000;
    var2 = var1 * var1 * (BME280_S64_t)dig_P6;
    var2 = var2 + ((var1*(BME280_S64_t)dig_P5)<<17);
    var2 = var2 + (((BME280_S64_t)dig_P4)<<35);
    var1 = ((var1 * var1 * (BME280_S64_t)dig_P3)>>8) + ((var1 * (BME280_S64_t)dig_P2)<<12);
    var1 = (((((BME280_S64_t)1)<<47)+var1))*((BME280_S64_t)dig_P1)>>33;
    if (var1 == 0) { return 0; }
    p = 1048576-adc_P;
    p = (((p<<31)-var2)*3125)/var1;
    var1 = (((BME280_S64_t)dig_P9) * (p>>13) * (p>>13)) >> 25;
    var2 = (((BME280_S64_t)dig_P8) * p) >> 19;
    p = ((p + var1 + var2) >> 8) + (((BME280_S64_t)dig_P7)<<4);
    return (BME280_U32_t)p;
}
```

**Humidity** (returns %RH as Q22.10, e.g. "47445" = 46.333 %RH):

```c
BME280_U32_t bme280_compensate_H_int32(BME280_S32_t adc_H)
{
    BME280_S32_t v_x1_u32r;
    v_x1_u32r = (t_fine - ((BME280_S32_t)76800));
    v_x1_u32r = (((((adc_H << 14) - (((BME280_S32_t)dig_H4) << 20) - (((BME280_S32_t)dig_H5) *
        v_x1_u32r)) + ((BME280_S32_t)16384)) >> 15) * (((((((v_x1_u32r *
        ((BME280_S32_t)dig_H6)) >> 10) * (((v_x1_u32r * ((BME280_S32_t)dig_H3)) >> 11) +
        ((BME280_S32_t)32768))) >> 10) + ((BME280_S32_t)2097152)) * ((BME280_S32_t)dig_H2) +
        8192) >> 14));
    v_x1_u32r = (v_x1_u32r - (((((v_x1_u32r >> 15) * (v_x1_u32r >> 15)) >> 7) *
        ((BME280_S32_t)dig_H1)) >> 4));
    v_x1_u32r = (v_x1_u32r < 0 ? 0 : v_x1_u32r);
    v_x1_u32r = (v_x1_u32r > 419430400 ? 419430400 : v_x1_u32r);
    return (BME280_U32_t)(v_x1_u32r>>12);
}
```

## Initialization Sequence (I2C, Forced Mode)

1. Wait 2 ms after power-on
2. Read chip ID (0xD0), verify = 0x60
3. Soft reset (optional): write 0xB6 to 0xE0, wait 2 ms
4. Wait for NVM copy: poll 0xF3 bit 0 until 0
5. Read calibration: 0x88-0xA1 (26 bytes) and 0xE1-0xE7 (7 bytes)
6. Write ctrl_hum (0xF2): humidity oversampling
7. Write ctrl_meas (0xF4): temp/pressure oversampling + mode=forced (**must come after ctrl_hum**)
8. Wait for measurement: poll 0xF3 bit 3 or wait t_measure_max
9. Burst read 0xF7-0xFE (8 bytes)
10. Compensate: temperature first (for t_fine), then pressure, then humidity

**Ordering rule:** Always write ctrl_hum (0xF2) **before** ctrl_meas (0xF4).

## BMP280 Compatibility

| Register  | BMP280 | BME280 |
| --- | --- | --- |
| 0xD0 "id" | 0x56/0x57/0x58 | 0x60 |
| 0xF5 t_sb | 110: 2000ms, 111: 4000ms | 110: 10ms, 111: 20ms |

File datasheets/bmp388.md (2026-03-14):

# BMP388 -- Digital Pressure Sensor -- Technical Reference

**Manufacturer:** Bosch Sensortec
**Document:** BST-BMP388-DS001-07, Rev 1.7, November 2020
**Package:** 10-pin metal-lid LGA, 2.0 x 2.0 x 0.75 mm

## 1. Device Overview

The BMP388 is a digital barometric pressure and temperature sensor by Bosch Sensortec. It uses a piezo-resistive pressure sensing element and a mixed-signal ASIC that performs A/D conversion and provides factory-calibrated compensation data through a digital interface (I2C or SPI).

- **Pressure range:** 300 -- 1250 hPa
- **Temperature range (operational):** -40 to +85 C
- **Temperature range (full accuracy):** 0 to +65 C
- **Chip ID register value:** 0x50
- **Interfaces:** I2C (up to 3.4 MHz), SPI (3-wire and 4-wire, up to 10 MHz)
- **FIFO:** 512-byte buffer
- **Interrupts:** Data ready, FIFO watermark, FIFO full

---

## 2. Electrical Characteristics

### 2.1 Supply Voltages

| Parameter | Min  | Typ | Max | Unit |
| --- | ---- | --- | --- | ---- |
| VDD (analog supply) | 1.65 | 1.8 | 3.6 | V |
| VDDIO (digital interface supply) | 1.2  | 1.8 | 3.6 | V |

VDD and VDDIO may be energized in any order. The ramp-up slope must not be less than 10 ms.

### 2.2 Current Consumption

| Condition | Typ  | Max  | Unit |
| --- | ---- | ---- | ---- |
| Sleep mode | 2.0  | -- | uA |
| Pressure measurement (peak) | 700  | 800  | uA |
| Temperature measurement | 300  | 400  | uA |
| Ultra low power (x1/x1) @ 1 Hz forced | 3.4  | 7.4  | uA |
| Low power (x2/x1) @ 1 Hz forced | 4.8  | 9.3  | uA |
| Standard resolution (x4/x1) @ 1 Hz forced | 7.8  | 12.8 | uA |
| High resolution (x8/x1) @ 1 Hz forced | 13.8 | 19.5 | uA |
| Ultra high resolution (x16/x2) @ 1 Hz forced | 26.2 | 33.5 | uA |
| Highest resolution (x32/x2) @ 1 Hz forced | 46.4 | 59.2 | uA |

### 2.3 Accuracy

| Parameter | Value | Condition |
| --- | --- | --- |
| Relative accuracy | +/- 0.08 hPa (+/- 66 cm) | 900..1100 hPa, 25..40 C |
| Absolute accuracy | +/- 0.50 hPa | 300..1100 hPa, -20..+65 C |
| Temperature accuracy | +/- 0.30 C @ 25 C, +/- 0.50 C @ 0..65 C | |
| Temperature coefficient offset | +/- 0.75 Pa/K (0..55 C), +/- 1.0 Pa/K (-20..0 C) | 700-1100 hPa |
| Long-term stability | +/- 0.33 hPa | 12 months |

### 2.4 Resolution and Noise

Best achievable pressure resolution: 0.016 Pa (highest oversampling, lowest bandwidth).

**Pressure noise (RMS, in Pa):**

| Oversampling | IIR off | IIR 1 | IIR 3 | IIR 7 | IIR 15 | IIR 31 | IIR 63 | IIR 127 |
| --- | --- | ----- | ----- | ----- | --- | --- | --- | --- |
| x1 (ultra low) | 6.6 | 3.8 | 2.5 | 1.7 | 1.2 | 0.8 | 0.6 | 0.4 |
| x2 (low) | 4.3 | 2.5 | 1.6 | 1.1 | 0.8 | 0.5 | 0.4 | 0.3 |
| x4 (standard) | 3.2 | 1.8 | 1.2 | 0.8 | 0.6 | 0.4 | 0.3 | 0.2 |
| x8 (high) | 2.3 | 1.3 | 0.9 | 0.6 | 0.4 | 0.3 | 0.2 | 0.1 |
| x16 (ultra high) | 1.6 | 0.9 | 0.6 | 0.4 | 0.2 | 0.2 | 0.1 | 0.1 |
| x32 (highest) | 1.2 | 0.7 | 0.4 | 0.3 | 0.2 | 0.1 | 0.1 | <0.1 |

**Temperature noise (RMS, in C, IIR off):** 0.005 (x1 through x8), 0.004 (x16), 0.003 (x32).

---

## 3. Timing Requirements

### 3.1 Startup

- **Start-up time:** 2 ms (time to first communication after both VDD > 1.58V and VDDIO > 0.65V)
- After power-on reset, the sensor settles in **sleep mode**
- Completion of POR is indicated by `por_detected` bit (register 0x10, bit 0); cleared on read

### 3.2 Measurement Time

Conversion time formula (in microseconds):

```
T_conv = 234 + press_en * (392 + 2^osr_p * 2000) + temp_en * (313 + 2^osr_t * 2000)
```

| Oversampling | Press OS | Temp OS | Typ (ms) | Max (ms) | Max Rate (Hz) |
| --- | --- | --- | --- | --- | --- |
| Ultra low power | x1 | x1 | 4.82 | 5.70 | 175 |
| Low power | x2 | x1 | 6.84 | 7.96 | 126 |
| Standard resolution | x4 | x1 | 10.88 | 12.48 | 80 |
| High resolution | x8 | x1 | 18.69 | 21.53 | 46 |
| Ultra high resolution | x16 | x2 | 37.14 | 41.89 | 24 |
| Highest resolution | x32 | x2 | 69.46 | 78.09 | 13 |

### 3.3 Maximum Sampling Rate

- **f_sampling base:** 200 Hz
- **Normal mode:** sampling period = prescaler / 200 Hz (prescaler set via `odr_sel` register)
- **Forced mode:** maximum frequency = 1 / T_conv

---

## 4. Pin Descriptions

10-pin metal-lid LGA package:

| Pin | Name  | I/O Type | Description | I2C Connection |
| --- | ----- | --- | --- | --- |
| 1 | VDDIO | Supply | Digital interface supply | VDDIO |
| 2 | SCK | In | Serial clock input | SCL |
| 3 | VSS | Supply | Ground | GND |
| 4 | SDI | In/Out | Serial data | SDA |
| 5 | SDO | In/Out | Serial data output / I2C address select | SA0 (GND or VDDIO) |
| 6 | CSB | In | Chip select (active low) | VDDIO (or programmable pin driving VDDIO) |
| 7 | INT | Out | Interrupt output | Host INT input or DNC |
| 8 | VSS | Supply | Ground | GND |
| 9 | VSS | Supply | Ground | GND |
| 10  | VDD | Supply | Analog supply | VDD |

**I2C connection notes:**

- CSB must be connected to VDDIO (or a pin that drives VDDIO at POR) to select I2C mode
- SDA and SCL need external pull-ups (recommended 4.7 kOhm to VDDIO)
- Bypass caps: 100 nF on both VDD and VDDIO

---

## 5. I2C Interface Details

### 5.1 I2C Addresses

The 7-bit address is `111011X`:

| SDO Pin | Address (7-bit) | Address (8-bit write) | Address (8-bit read) |
| --- | --- | --- | --- |
| GND | 0x76 | 0xEC | 0xED |
| VDDIO | 0x77 | 0xEE | 0xEF |

The SDO pin must NOT be left floating -- the address will be undefined.

### 5.2 I2C Protocol

- Compatible with Philips I2C Specification Rev 6 (standard, fast, high speed modes)
- SCK frequency: 400 kHz (typ), max 3400 kHz
- SDA and SCL are NOT pure open-drain; they contain ESD protection diodes to VDDIO and GND
- Internal pull-up on CSB: 75-125 kOhm (typ 100 kOhm)
- Bus load capacitance on SDI and SCK: max 400 pF

### 5.3 I2C Watchdog

- Configurable via `IF_CONF` register (0x1A)
- `i2c_wdt_en` (bit 1): enable/disable watchdog timer
- `i2c_wdt_sel` (bit 2): short timeout (1.25 ms) or long timeout (40 ms)
- Backed by NVM

---

## 6. Power Modes

Controlled by `mode[1:0]` bits in `PWR_CTRL` register (0x1B, bits 5:4):

| mode[1:0] | Mode | Description |
| --- | --- | --- |
| 00 | Sleep  | Default after POR. No measurements. All registers accessible. Minimum current. |
| 01 or 10  | Forced | Single measurement, then returns to sleep. Must re-trigger for each reading. |
| 11 | Normal | Continuous cyclic measurements at rate set by ODR register. |

### 6.1 Mode Transitions

- Power-on always enters Sleep
- Sleep -> Forced: write mode=01 or mode=10
- Sleep -> Normal: write mode=11
- Normal -> Sleep: write mode=00
- Forced -> Sleep: automatic after measurement completes
- If a measurement is in progress, mode switching is delayed until it completes

---

## 7. Measurement Configuration

### 7.1 Enabling Sensors

In `PWR_CTRL` register (0x1B):

- Bit 0 (`press_en`): 0 = pressure disabled, 1 = pressure enabled
- Bit 1 (`temp_en`): 0 = temperature disabled, 1 = temperature enabled

### 7.2 Oversampling (register 0x1C "OSR")

**Pressure oversampling** -- bits [2:0] (`osr_p`):

| osr_p | Oversampling | Resolution | Noise (Pa, IIR off) |
| ----- | --- | --- | --- |
| 000 | x1 | 16 bit / 2.64 Pa  | 6.6 |
| 001 | x2 | 17 bit / 1.32 Pa  | 4.3 |
| 010 | x4 | 18 bit / 0.66 Pa  | 3.2 |
| 011 | x8 | 19 bit / 0.33 Pa  | 2.3 |
| 100 | x16 | 20 bit / 0.17 Pa  | 1.6 |
| 101 | x32 | 21 bit / 0.085 Pa | 1.2 |

**Temperature oversampling** -- bits [5:3] (`osr_t`):

| osr_t | Oversampling | Resolution |
| ----- | --- | --- |
| 000 | x1 | 16 bit / 0.0050 C  |
| 001 | x2 | 17 bit / 0.0025 C  |
| 010 | x4 | 18 bit / 0.0012 C  |
| 011 | x8 | 19 bit / 0.0006 C  |
| 100 | x16 | 20 bit / 0.0003 C  |
| 101 | x32 | 21 bit / 0.00015 C |

**Recommendation:** Temperature oversampling above x2 does not significantly improve compensated pressure accuracy.

### 7.3 IIR Filter (register 0x1F "CONFIG")

Bits [3:1] (`iir_filter`):

| Value | Coefficient |
| ----- | --- |
| 000 | 0 (bypass / off) |
| 001 | 1 |
| 010 | 3 |
| 011 | 7 |
| 100 | 15 |
| 101 | 31 |
| 110 | 63 |
| 111 | 127 |

Filter formula: `data_filtered = (data_filtered_old * coeff + data_ADC) / (coeff + 1)`

Writing to the filter register resets the filter. The filter is also reset when `temp_en` or `press_en` changes from 1 to 0, or on sleep-to-normal transition.

### 7.4 Output Data Rate (register 0x1D "ODR")

Bits [4:0] (`odr_sel`), prescaler = 2^odr_sel, f_sampling = 200 Hz:

| odr_sel | Prescaler | ODR | Sampling Period |
| --- | --- | --- | --- |
| 0x00 | 1 | 200 Hz | 5 ms |
| 0x01 | 2 | 100 Hz | 10 ms |
| 0x02 | 4 | 50 Hz | 20 ms |
| 0x03 | 8 | 25 Hz | 40 ms |
| 0x04 | 16 | 12.5 Hz | 80 ms |
| 0x05 | 32 | 6.25 Hz | 160 ms |
| 0x06 | 64 | 3.125 Hz | 320 ms |
| 0x07 | 127 | 1.5625 Hz | 640 ms |
| 0x08 | 256 | 0.78125 Hz  | 1.28 s |
| 0x09 | 512 | 0.390625 Hz | 2.56 s |
| ... | ... | ... | ... |
| 0x11 | 131072 | 0.0015 Hz | 655.36 s |

Values above 0x11 are saturated at 0x11.

### 7.5 Recommended Settings by Use Case

| Use Case | Mode | osr_p | osr_t | IIR coeff | ODR (Hz) | Current (uA) | Noise (cm) |
| --- | --- | ----- | ----- | --- | --- | --- | --- |
| Weather monitoring (lowest power) | Forced | x1 | x1 | Off | 1/60 | 4 | 55 |
| Drop detection | Normal | x2 | x1 | Off | 100 | 358 | 36 |
| Indoor navigation | Normal | x16 | x2 | 4 | 25 | 560 | 5 |
| Drone | Normal | x8 | x1 | 2 | 50 | 570 | 11 |
| Handheld low-power | Normal | x8 | x1 | 2 | 12.5 | 145 | 11 |
| Handheld dynamic | Normal | x4 | x1 | 4 | 50 | 310 | 10 |

---

## 8. Register Map

All registers are 8-bit. Reserved bits should not be written.

| Address | Name | Default | R/W | Description |
| --- | --- | --- | --- | --- |
| 0x00 | CHIP_ID | 0x50 | R | Chip identification |
| 0x02 | ERR_REG | 0x00 | R | Error flags: fatal_err (bit 0), cmd_err (bit 1), conf_err (bit 2). Cleared on read. |
| 0x03 | STATUS | 0x00 | R | cmd_rdy (bit 4), drdy_press (bit 5), drdy_temp (bit 6). drdy bits reset when DATA register is read. |
| 0x04 | DATA_0 | 0x00 | R | Pressure XLSB [7:0] |
| 0x05 | DATA_1 | 0x00 | R | Pressure LSB [15:8] |
| 0x06 | DATA_2 | 0x80 | R | Pressure MSB [23:16] |
| 0x07 | DATA_3 | 0x00 | R | Temperature XLSB [7:0] |
| 0x08 | DATA_4 | 0x00 | R | Temperature LSB [15:8] |
| 0x09 | DATA_5 | 0x80 | R | Temperature MSB [23:16] |
| 0x0C | SENSORTIME_0 | 0x00 | R | Sensor time [7:0] |
| 0x0D | SENSORTIME_1 | 0x00 | R | Sensor time [15:8] |
| 0x0E | SENSORTIME_2 | 0x00 | R | Sensor time [23:16] |
| 0x10 | EVENT | 0x01 | R | por_detected (bit 0): set after POR or soft reset. Cleared on read. |
| 0x11 | INT_STATUS | 0x00 | R | fwm_int (bit 0), ffull_int (bit 1), drdy (bit 3). Cleared on read. |
| 0x12 | FIFO_LENGTH_0 | 0x00 | R | FIFO byte counter [7:0] |
| 0x13 | FIFO_LENGTH_1 | 0x00 | R | FIFO byte counter [8] (bit 0 only) |
| 0x14 | FIFO_DATA | 0x00 | R | FIFO data output port |
| 0x15 | FIFO_WTM_0 | 0x01 | RW  | FIFO watermark [7:0] |
| 0x16 | FIFO_WTM_1 | 0x00 | RW  | FIFO watermark [8] (bit 0 only) |
| 0x17 | FIFO_CONFIG_1 | 0x02 | RW  | fifo_mode (bit 0), fifo_stop_on_full (bit 1), fifo_time_en (bit 2), fifo_press_en (bit 3), fifo_temp_en (bit 4) |
| 0x18 | FIFO_CONFIG_2 | 0x02 | RW  | fifo_subsampling [2:0], data_select [4:3] |
| 0x19 | INT_CTRL | 0x02 | RW  | int_od (bit 0), int_level (bit 1), int_latch (bit 2), fwtm_en (bit 3), ffull_en (bit 4), drdy_en (bit 6) |
| 0x1A | IF_CONF | 0x00 | RW  | spi3 (bit 0), i2c_wdt_en (bit 1), i2c_wdt_sel (bit 2) |
| 0x1B | PWR_CTRL | 0x00 | RW  | press_en (bit 0), temp_en (bit 1), mode [5:4] |
| 0x1C | OSR | 0x02 | RW  | osr_p [2:0], osr_t [5:3] |
| 0x1D | ODR | 0x00 | RW  | odr_sel [4:0] |
| 0x1F | CONFIG | 0x00 | RW  | iir_filter [3:1] |
| 0x30-0x57 | Calibration data | -- | R | 40 bytes of factory calibration coefficients |
| 0x7E | CMD | 0x00 | W | Command register (always reads 0x00) |

### 8.1 CMD Register Commands (0x7E)

| Value | Name | Description |
| ----- | --- | --- |
| 0x00  | nop | No operation |
| 0x34  | extmode_en_middle | See datasheet |
| 0xB0  | fifo_flush | Flush FIFO; does not change FIFO_CONFIG |
| 0xB6  | softreset | Full software reset; all registers return to defaults |

---

## 9. Calibration Coefficients

### 9.1 Trimming Coefficient Memory Map (registers 0x31 -- 0x45)

| Addr (hex) | Content | Coefficient | Size | Signedness |
| --- | --- | --- | --- | --- |
| 0x31-0x32  | NVM_PAR_T1  | PAR_T1 | 16 bit | unsigned |
| 0x33-0x34  | NVM_PAR_T2  | PAR_T2 | 16 bit | unsigned |
| 0x35 | NVM_PAR_T3  | PAR_T3 | 8 bit  | signed |
| 0x36-0x37  | NVM_PAR_P1  | PAR_P1 | 16 bit | signed |
| 0x38-0x39  | NVM_PAR_P2  | PAR_P2 | 16 bit | signed |
| 0x3A | NVM_PAR_P3  | PAR_P3 | 8 bit  | signed |
| 0x3B | NVM_PAR_P4  | PAR_P4 | 8 bit  | signed |
| 0x3C-0x3D  | NVM_PAR_P5  | PAR_P5 | 16 bit | unsigned |
| 0x3E-0x3F  | NVM_PAR_P6  | PAR_P6 | 16 bit | unsigned |
| 0x40 | NVM_PAR_P7  | PAR_P7 | 8 bit  | signed |
| 0x41 | NVM_PAR_P8  | PAR_P8 | 8 bit  | signed |
| 0x42-0x43  | NVM_PAR_P9  | PAR_P9 | 16 bit | signed |
| 0x44 | NVM_PAR_P10 | PAR_P10 | 8 bit  | signed |
| 0x45 | NVM_PAR_P11 | PAR_P11 | 8 bit  | signed |

### 9.2 Coefficient Conversion (NVM raw -> floating point)

**Temperature coefficients:**

```
PAR_T1 = NVM_PAR_T1 / 2^-8       (i.e. NVM_PAR_T1 * 256.0)
PAR_T2 = NVM_PAR_T2 / 2^30
PAR_T3 = NVM_PAR_T3 / 2^48
```

**Pressure coefficients:**

```
PAR_P1  = (NVM_PAR_P1 - 2^14) / 2^20
PAR_P2  = (NVM_PAR_P2 - 2^14) / 2^29
PAR_P3  = NVM_PAR_P3  / 2^32
PAR_P4  = NVM_PAR_P4  / 2^37
PAR_P5  = NVM_PAR_P5  / 2^-3      (i.e. NVM_PAR_P5 * 8.0)
PAR_P6  = NVM_PAR_P6  / 2^6
PAR_P7  = NVM_PAR_P7  / 2^8
PAR_P8  = NVM_PAR_P8  / 2^15
PAR_P9  = NVM_PAR_P9  / 2^48
PAR_P10 = NVM_PAR_P10 / 2^48
PAR_P11 = NVM_PAR_P11 / 2^65
```

### 9.3 Temperature Compensation Algorithm

Input: `uncomp_temp` (unsigned 24-bit raw value from DATA_3/4/5)
Output: compensated temperature in degrees C (float)

```c
float partial_data1 = (float)(uncomp_temp - par_t1);
float partial_data2 = (float)(partial_data1 * par_t2);
// t_lin is stored for pressure compensation
t_lin = partial_data2 + (partial_data1 * partial_data1) * par_t3;
return t_lin;  // compensated temperature in C
```

### 9.4 Pressure Compensation Algorithm

Input: `uncomp_press` (unsigned 24-bit raw value from DATA_0/1/2), and `t_lin` from temperature compensation
Output: compensated pressure in Pa (float)

```c
// partial_out1
partial_data1 = par_p6 * t_lin;
partial_data2 = par_p7 * (t_lin * t_lin);
partial_data3 = par_p8 * (t_lin * t_lin * t_lin);
partial_out1  = par_p5 + partial_data1 + partial_data2 + partial_data3;

// partial_out2
partial_data1 = par_p2 * t_lin;
partial_data2 = par_p3 * (t_lin * t_lin);
partial_data3 = par_p4 * (t_lin * t_lin * t_lin);
partial_out2  = (float)uncomp_press *
                (par_p1 + partial_data1 + partial_data2 + partial_data3);

// partial_data4
partial_data1 = (float)uncomp_press * (float)uncomp_press;
partial_data2 = par_p9 + par_p10 * t_lin;
partial_data3 = partial_data1 * partial_data2;
partial_data4 = partial_data3 +
                ((float)uncomp_press * (float)uncomp_press * (float)uncomp_press) * par_p11;

comp_press = partial_out1 + partial_out2 + partial_data4;
return comp_press;  // compensated pressure in Pa
```

**IMPORTANT:** Temperature must always be compensated first, as `t_lin` is required for pressure compensation.

---

## 10. Data Readout

### 10.1 Burst Read

Use a burst read from register 0x04 through 0x09 (6 bytes) to read both pressure and temperature atomically. Data register shadowing ensures consistency only when a single burst read covers all data registers.

Pressure (unsigned 24-bit): `(DATA_2 << 16) | (DATA_1 << 8) | DATA_0`
Temperature (unsigned 24-bit): `(DATA_5 << 16) | (DATA_4 << 8) | DATA_3`

### 10.2 Data Ready Checking

Two methods:

1. **Polling:** Read STATUS register (0x03): `drdy_press` (bit 5), `drdy_temp` (bit 6). These bits are reset when any corresponding DATA register is read.
2. **Interrupt:** Enable `drdy_en` in INT_CTRL (0x19, bit 6). Read INT_STATUS (0x11, bit 3) to check/clear.

---

## 11. Initialization Sequence

A typical driver initialization for forced-mode weather monitoring:

1. **Wait for startup:** 2 ms after power supplies reach threshold
2. **Read CHIP_ID** (0x00): verify it returns **0x50**
3. **Soft reset:** write 0xB6 to CMD register (0x7E); wait 2 ms; read EVENT register (0x10) to confirm `por_detected`
4. **Read calibration data:** burst read 0x31-0x45 (21 bytes); parse into NVM*PAR_T1..NVM_PAR_P11; convert to floating-point PAR*\* coefficients
5. **Configure oversampling:** write OSR register (0x1C) -- e.g., 0x00 for x1/x1
6. **Configure IIR filter:** write CONFIG register (0x1F) -- e.g., 0x00 for off
7. **Configure ODR** (if using normal mode): write ODR register (0x1D)
8. **Configure interrupts** (optional): write INT_CTRL register (0x19)
9. **Enable sensors and set mode:** write PWR_CTRL register (0x1B)
   - For forced mode: `0x13` = press_en + temp_en + mode=forced (bits: 0001 0011)
   - For normal mode: `0x33` = press_en + temp_en + mode=normal (bits: 0011 0011)
10. **Wait for measurement** (forced mode): poll STATUS register for `drdy_press` and `drdy_temp`, or wait for the maximum conversion time
11. **Read data:** burst read 0x04-0x09
12. **Compensate:** run temperature compensation, then pressure compensation

For forced mode, repeat from step 9 for each new measurement.

---

## 12. FIFO

- 512-byte buffer; enabled via FIFO_CONFIG_1 (0x17)
- Each frame has a 1-byte header followed by data bytes
- Sensor frame (temp+press): 7 bytes (1 header + 3 temp + 3 press)
- Sensor frame (temp or press only): 4 bytes
- Frame header bit 7 is always 1 for sensor frames; bits [4:3] indicate time/temp/press enables
- Overflow: configurable to either overwrite oldest (streaming) or stop (fifo_stop_on_full)
- Flush: write 0xB0 to CMD register, or soft reset (0xB6)
- Read via repeated reads of FIFO_DATA register (0x14) -- address stays at 0x14 during burst

---

## 13. Interface Electrical Summary

| Parameter | Min | Typ | Max | Unit |
| --- | --- | --- | --- | ---- |
| Input low level (SCK, SDI, CSB) | -- | --  | 0.25 \* VDDIO | V |
| Input high level (SCK, SDI, CSB) | 0.7 \* VDDIO | --  | -- | V |
| Output low level (SDI, SDO, INT @ 3 mA)  | -- | --  | 0.2 \* VDDIO  | V |
| Output high level (SDI, SDO, INT @ 1 mA) | 0.8 \* VDDIO | --  | -- | V |
| CSB internal pull-up | 75 | 100 | 125 | kOhm |

**Warning:** Holding any interface pin (SDI, SDO, SCK, CSB) high when VDDIO is off can permanently damage the device through ESD protection diode current flow.

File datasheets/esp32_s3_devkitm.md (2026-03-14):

# ESP32-S3-DevKitM-1U

No local datasheet -- see online user guides:

- https://docs.espressif.com/projects/esp-dev-kits/en/latest/esp32s3/esp32-s3-devkitm-1/user_guide.html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
- https://docs.espressif.com/projects/esp-dev-kits/en/latest/esp32s3/esp32-s3-devkitm-1/user_guide.html

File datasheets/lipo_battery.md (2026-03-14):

# LiPo Battery (Seamuing 7649083)

3.7V 10000mAh lithium polymer battery with PH2.0A connector.

## Specifications

| Parameter | Value |
| --- | --- |
| Voltage | 3.7V |
| Capacity | 10000 mAh |
| Max operating current  | 3A |
| Overcurrent protection | 1.8-2.1A |
| Dimensions | 115 x 65 x 8.8 mm |
| Weight | 155g |
| Connector | PH2.0A |

## Charging

- Constant current at 4.25V, 0.2C
- Then constant voltage at 4.2V until current <= 0.05C

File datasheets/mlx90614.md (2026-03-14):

# MLX90614 -- Infrared Non-Contact Thermometer

**Manufacturer:** Melexis
**Package:** TO-39

## Device Overview

Factory-calibrated infrared (IR) non-contact thermometer. Integrates an IR thermopile detector and signal-conditioning ASSP. Outputs linearized temperature via SMBus or PWM.

- **Ambient temperature range:** -40 to +125 C
- **Object temperature range:** -70 to +380 C
- **Resolution:** 0.02 C
- **Accuracy:** +/-0.5 C (0..+50 C), medical version +/-0.2 C (36..38 C)
- **Factory emissivity:** 1.0 (adjustable 0.1..1.0)
- **Variants:** single-zone (xAx), dual-zone (xBx), 5V (Axx), 3V (Bxx/Dxx)
- **Optical filter:** 5.5..14 um

## Pin Description (TO-39, bottom view)

| Pin | Name | Description |
| --- | --- | --- |
| 1 | SCL/Vz  | SMBus clock (5.7V Zener on Axx) |
| 2 | SDA/PWM | SMBus data / PWM output (open drain) |
| 3 | VDD | Positive supply |
| 4 | VSS | Ground |

## Electrical Characteristics

### 5V Version (Axx)

| Parameter | Min | Typ | Max | Unit |
| --- | --- | --- | --- | ---- |
| VDD | 4.5 | 5.0 | 5.5 | V |
| IDD | --  | 1.3 | 2.5 | mA |
| Output valid after POR | --  | --  | 250 | ms |

### 3V Version (Bxx/Dxx)

| Parameter | Min | Typ | Max | Unit |
| --- | --- | --- | --- | ---- |
| VDD | 2.6 | 3.0 | 3.6 | V |
| IDD | --  | 1.3 | 2.5 | mA |
| Sleep current | --  | 2 | 6 | uA |
| Output valid after POR | --  | --  | 250 | ms |

## SMBus Protocol

- **Protocol:** SMBus (subset of I2C), device is always slave
- **Clock:** 10 kHz to 100 kHz
- **Default address:** 0x5A (7-bit), stored in EEPROM 0x0E
- **General call:** address 0x00 (all devices respond)
- **Data format:** 16-bit words (LSByte first) + 8-bit PEC (CRC-8, polynomial X8+X2+X1+1)
- **Commands:** Read Word and Write Word only

### Command Opcodes

| Opcode | Command |
| --- | --- |
| 0x00-0x1F | RAM access (bits [4:0] = address) |
| 0x20-0x3F | EEPROM access (bits [4:0] = address) |
| 0xF0 | Read flags |
| 0xFF | Enter SLEEP (3V only, PEC=0xE8 for SA=0x5A) |

### Read Word Sequence

```
S [SA_W] ACK [Command] ACK Sr [SA_R] ACK [LSB] ACK [MSB] ACK [PEC] NACK P
```

### Write Word Sequence

```
S [SA_W] ACK [Command] ACK [LSB] ACK [MSB] ACK [PEC] ACK P
```

### Timing

| Parameter | Value |
| --- | --- |
| SMBus request (t_REQ) | >= 1.44 ms (SCL low) |
| Timeout low (SCL) | <= 27 ms |
| Wake-up request | >= 33 ms (SCL low) |
| Data available after wake | ~250 ms |

## Memory Map

### RAM (read-only via SMBus)

| Address | Name | Description |
| --- | --- | --- |
| 0x06 | TA | Linearized ambient temperature |
| 0x07 | TOBJ1 | Linearized object temperature, sensor 1 |
| 0x08 | TOBJ2 | Object temperature, sensor 2 (dual-zone only) |
| 0x04 | Raw IR ch1 | Raw IR data |
| 0x05 | Raw IR ch2 | Raw IR data |

**Temperature conversion:** `T [C] = RAM_value * 0.02 - 273.15`

MSB (bit 15) is an error flag -- if set, reading is invalid.

### EEPROM (selected cells writable)

| Address | Name | Write | Description |
| --- | --- | ----- | --- |
| 0x04 | Emissivity | Yes | Default 0xFFFF = 1.0 |
| 0x05 | Config Register 1 | Yes | Main configuration |
| 0x0E | SMBus address | Yes | LSB bits [6:0] |
| 0x1C-0x1F | ID number | No | 64-bit unique ID |

### EEPROM Write Procedure

1. Write 0x0000 to target cell (erase)
2. Wait >= 5 ms (10 ms recommended)
3. Read back and verify
4. Write new value
5. Wait >= 5 ms
6. Read back and verify
7. Power cycle

Endurance: 100,000 cycles. Retention: 10 years at 85 C.

## Emissivity Setting

- Formula: `EEPROM_value = round(65535 * emissivity)`
- Example: 0.95 -> 0xF332

## Configuration Register 1 (EEPROM 0x05)

| Bits | Field | Values |
| --- | --- | --- |
| B0 | Self-test | 0=enabled, 1=disabled |
| B2-B4 | Amplifier gain  | 000=1, 001=3, 010=6, 011=12.5, 100=25, 101=50, 110/111=100 |
| B5-B7 | FIR filter | 100=128, 101=256, 110=512, 111=1024 |
| B8 | IR sensor count | 0=single, 1=dual |
| B13-B15 | IIR filter | 000=50%, 001=25%, 100=bypass |

**Do not modify bits [14:11, 7:3] without Melexis tools** -- cancels factory calibration.

## PEC (CRC-8) Calculation

- Polynomial: X^8 + X^2 + X^1 + 1 (0x107, init 0x00)
- Read: PEC over [SA_W, Command, SA_R, LSByte, MSByte]
- Write: PEC over [SA_W, Command, LSByte, MSByte]

## Initialization and Reading

### Minimal Init (SMBus, defaults)

No special init needed. After power-on:

1. Wait 250 ms for valid data
2. (Optional) Read flags (0xF0), check bit 3 = 1
3. Begin reading

### Reading Object Temperature

```
smbus_read_word(0x5A, 0x07) -> (lsb, msb, pec)
raw = (msb << 8) | lsb
if (raw & 0x8000) != 0 { error }
temp_celsius = raw * 0.02 - 273.15
```

### Sleep Mode (3V only)

- **Enter:** write command 0xFF (PEC=0xE8 for SA=0x5A)
- **Exit:** SCL low >= 33 ms, then wait 250 ms

## Application Notes

- 100 nF decoupling on VDD
- Pull-ups on SDA and SCL
- Continuous reads introduce noise; read less frequently than refresh rate
- VDD compensation (3V): `T_comp = T_meas - (VDD - 3.0) * 0.6` C/V
- Max 127 devices on one bus

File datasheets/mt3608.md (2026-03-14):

# MT3608 -- Step-Up (Boost) DC-DC Converter

**Manufacturer:** Aerosemi Technology
**Package:** SOT23-6

## Device Overview

Fixed 1.2 MHz, current-mode step-up converter with integrated 80 mOhm N-channel MOSFET. Designed for small, low-power applications.

- Internal soft-start
- Auto PFM at light loads
- UVLO, current limiting (4A peak), thermal shutdown (155 C)
- Up to 97% efficiency

## Pin Descriptions

| Pin | Name | Function |
| --- | ---- | --- |
| 1 | SW | Power switch output (inductor + diode) |
| 2 | GND  | Ground |
| 3 | FB | Feedback input (0.6V reference) |
| 4 | EN | Enable (high=on, low=off, tie to IN if unused) |
| 5 | IN | Input supply |
| 6 | NC | No connection |

## Electrical Characteristics

| Parameter | Min | Typ | Max | Unit |
| --- | ----- | --- | ----- | ---- |
| Input voltage | 2 | --  | 24 | V |
| UVLO threshold | -- | --  | 1.98  | V |
| Shutdown current (EN=0) | -- | 0.1 | 1 | uA |
| Switching frequency | -- | 1.2 | -- | MHz  |
| Max duty cycle | 90 | --  | -- | % |
| FB reference | 0.588 | 0.6 | 0.612 | V |
| SW on-resistance | -- | 80  | 150 | mOhm |
| SW current limit | -- | 4 | -- | A |
| Thermal shutdown | -- | 155 | -- | C |

## Output Voltage Formula

```
V_OUT = V_REF * (1 + R1 / R2)    where V_REF = 0.6V
```

R1: V_OUT to FB. R2: FB to GND.

| V_OUT | R2 | R1 |
| ----- | ---- | ---- |
| 3.3V  | 100k | 450k |
| 5V | 100k | 733k |
| 12V | 100k | 1.9M |

## Typical Application Circuit

```
        L1 (4.7-22uH)
VIN ---+---/\/\/---+---[D1]---+--- VOUT
       |           |          |
      [C1]      [SW]        [C2]
      22uF     [MT3608]     22uF
       |       [IN][EN]      |
      GND       |   |       GND
               GND  VIN
              [FB]---+
                     |
                    [R1] (to VOUT)
                     |
                    [R2] (to GND)
```

## Component Selection

- **Inductor:** 4.7-22 uH, low core loss at 1.2 MHz, saturation > 4A
- **Capacitors:** 22 uF ceramic (X5R/X7R), low ESR, close to IC
- **Diode:** Schottky, reverse voltage > V_OUT
- **Feedback resistors:** 1% tolerance, close to FB pin

## Efficiency

- **5V->12V:** peak ~93.5% at 200 mA, >88% from 100-500 mA
- **13V->18V:** 91-94% from 100-1700 mA
- Efficiency improves with lower boost ratios

## Layout

- Input/output caps close to IC on ground plane
- SW trace small to minimize EMI
- FB resistors close to FB pin, away from SW

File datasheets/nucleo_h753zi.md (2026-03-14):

# NUCLEO-H753ZI Technical Reference

**Sources:** DB3171 Rev 18, UM2407 Rev 5
**Board:** MB1364
**MCU:** STM32H753ZIT6 (LQFP144)

## MCU Specifications

| Feature | Value |
| --- | --- |
| Core | Arm Cortex-M7 with FPU |
| Flash | 2 MB |
| Special | Hardware crypto accelerator |
| I/O voltage | 3.3V (NOT 5V tolerant) |

## Clock Configuration

### HSE (default)

**8 MHz MCO from ST-LINK** (not a crystal). Configurable via solder bridges SB3/SB4/SB44/SB45/SB46.

### LSE

**32.768 kHz on-board crystal (X2)**.

## Power Supply

### Source Selection (JP2)

| JP2 | Source | Voltage | Max Current |
| --- | --- | --- | --- |
| [1-2] **default** | ST-LINK USB (CN1) | 5V | 500 mA |
| [3-4] | VIN (CN8-15, CN11-24) | 7-12V | 250-800 mA  |
| [5-6] | 5V_EXT (CN11-6) | 4.75-5.25V | 500 mA |
| [7-8] | USB charger | 5V | -- |

If board + shields > 300 mA, use external supply.

### VDD_MCU (JP5)

| JP5 | Level |
| --- | ----- |
| [1-2] **default** | 3.3V  |
| [2-3] | 1.8V  |

## Debug (STLINK-V3E)

- USB 2.0 high-speed via CN1
- SWD + JTAG + SWO trace
- VCP via **USART3 (PD8 TX / PD9 RX)** by default
- MIPI-10 connector CN5

## LEDs

| LED | Color | Pin  | Function |
| --- | --- | ---- | --- |
| LD1 | Green | PB0  | User (HIGH=on) |
| LD2 | Yellow | PE1  | User |
| LD3 | Red | PB14 | User |
| LD4 | Tricolor | -- | ST-LINK status |
| LD5 | Green | -- | Power (+5V) |

## Push-Buttons

| Button | Pin  | Function |
| --- | ---- | --- |
| B1 (USER)  | PC13 | User (blue) |
| B2 (RESET) | NRST | Hardware reset |

## Jumper Summary

| Jumper | Function | Default |
| --- | --- | --- |
| JP1 | STLK_RST | OFF |
| JP2 | Power source | [1-2] STLINK |
| JP3 | NRST to ST-LINK | ON |
| JP4 | IDD measurement | ON |
| JP5 | VDD_MCU | [1-2] 3V3 |
| JP6 | Ethernet TXD1 | ON |

## Connector Pinout (Key Pins)

### CN7

| Pin | Name | STM32 | Function |
| --- | ---- | --- | --- |
| 2 | D15  | **PB8** | **I2C1_SCL** |
| 4 | D14  | **PB9** | **I2C1_SDA** |
| 10  | D13  | PA5 | SPI1_SCK |
| 12  | D12  | PA6 | SPI1_MISO |
| 14  | D11  | PB5 | SPI1_MOSI |
| 17  | D24  | **PA4** | **SPI_B_NSS (BLE RST_N)** |

### CN8

| Pin | Name | STM32 | Function |
| --- | ---- | --- | --- |
| 7 | 3V3  | -- | 3.3V output |
| 9 | 5V | -- | 5V output |
| 14  | D49  | **PG2** | **External LED** |
| 15  | VIN  | -- | 7-12V input |

### CN9

| Pin | Name | STM32 | Function |
| --- | ---- | --- | --- |
| 1 | A0 | PA3 | ADC |
| 4 | D52  | **PD6** | **USART2_RX**  |
| 6 | D53  | **PD5** | **USART2_TX**  |
| 8 | D54  | **PD4** | **USART2_RTS** |
| 10  | D55  | **PD3** | **USART2_CTS** |

### CN10

| Pin | Name | STM32 | Function |
| --- | ---- | --- | --- |
| 14  | D1 | PB6 | LPUART1 TX |
| 16  | D0 | PB7 | LPUART1 RX |
| 31  | D33  | **PB0** | **LD1 green LED** |

## Project Pin Cross-Reference

| Function | STM32 Pin | Connector |
| --- | --- | --- |
| LED green (LD1) | PB0 | CN10-31 |
| LED yellow (LD2) | PE1 | onboard |
| LED red (LD3) | PB14 | onboard |
| External LED | PG2 | CN8-14 |
| I2C1_SCL (BMP388) | PB8 | CN7-2 |
| I2C1_SDA (BMP388) | PB9 | CN7-4 |
| USART2_TX (RN4871)  | PD5 | CN9-6 |
| USART2_RX (RN4871)  | PD6 | CN9-4 |
| USART2_RTS (RN4871) | PD4 | CN9-8 |
| USART2_CTS (RN4871) | PD3 | CN9-10 |
| BLE RST_N (RN4871)  | PA4 | CN7-17 |

## Gotchas

1. **3.3V I/O only** -- no 5V tolerance
2. HSE is 8 MHz from ST-LINK MCO, not a crystal
3. USB CN13 cannot power the board -- power first, then connect
4. Ethernet ties up PA1, PA2, PA7, PC1, PC4, PC5, PG11, PG13, PB13
5. VCP default is USART3 (PD8/PD9), not LPUART1
6. PA13/PA14 are SWD -- don't use as GPIO while debugging
7. Power sequencing with external supply: power board first, then USB

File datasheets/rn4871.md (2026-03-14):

# RN4870/RN4871 BLE Module -- Technical Reference

**Manufacturer:** Microchip
**Sources:** DS50002489A (Data Sheet), DS50002466C (User Guide)

## Device Overview

Bluetooth 4.2 Low Energy modules based on Microchip IS1870 SoC. Host MCU controls them via ASCII commands over UART.

### RN4870 vs RN4871

| Feature | RN4870 | RN4871 |
| --- | --- | --- |
| Size | 12x22 mm | 9x11.5 mm |
| Pins | 33 | 16 |
| SPI | Yes | No |
| PWM | Up to 3  | No |
| ADC channels | 6 | 4 |
| I2C | Yes | Yes |

---

## UART Protocol

### Default Settings

| Parameter | Value |
| --- | --- |
| Baud Rate | 115200 |
| Data Bits | 8 |
| Parity | None |
| Stop Bits | 1 |
| Flow Control | Disabled |

### Baud Rates (SB command)

| Setting | Rate |
| --- | --- |
| 00 | 921600 |
| 01 | 460800 |
| 02 | 230400 |
| **03**  | **115200 (default)** |
| 04 | 57600 |
| 05 | 38400 |
| 07 | 19200 |
| 09 | 9600 |

### Command Protocol

- Commands end with `\r` (0x0D), no line feed
- 1-3 case-insensitive ASCII chars + optional params separated by commas
- Wait for response before sending next command
- Success: `AOK\r\n`, failure: `ERR\r\n`
- Prompt: `CMD> ` (unless suppressed with SR bit 0x4000)

---

## Operating Modes

### Data Mode (default)

UART data passes through to BLE peer via Transparent UART service.

### Command Mode

- **Enter:** `$$$` (100 ms delay before first `$`). Response: `CMD>`
- **Exit:** `---\r`. Response: `END`

### Fast Data Mode (SR bit 0x2000)

`$$$` disabled. Use PIO pin configured as "UART Mode Switch" (function 0x0C).

---

## Command Reference

### Set Commands (stored in NVM, need reboot)

| Command | Description |
| --- | --- |
| `SN,<text>` | Device name (up to 20 chars) |
| `SS,<hex8>` | Default services bitmap |
| `SR,<hex16>` | Feature bitmap |
| `SA,<0-5>` | Authentication I/O capability |
| `SB,<hex8>` | UART baud rate |
| `SP,<pin>` | Security PIN (default: 000000) |
| `SF,1` | Factory reset (keep services). Immediate reboot. |
| `SF,2` | Full factory reset. Immediate reboot. |
| `SGA,<0-5>` | TX power during advertising |
| `SGC,<0-5>` | TX power during connection |
| `SO,<0,1>` | Low-power mode (32 kHz clock) |
| `ST,<min>,<max>,<lat>,<to>` | Connection parameters |
| `STA,<fast_int>,<fast_to>,<slow_int>` | Advertisement timing |
| `SW,<pin>,<func>` | Pin function configuration |

### SR -- Feature Bitmap

| Bit | Feature |
| --- | --- |
| 0x8000 | Hardware flow control (CTS/RTS) |
| 0x4000 | No Prompt |
| 0x2000 | Fast Mode (no $$$) |
| 0x0100 | UART Transparent without ACK |
| 0x0080 | Reboot after Disconnection |
| 0x0040 | Running Script after Power On |
| 0x0020 | MLDP streaming service |
| 0x0010 | Disable DLE (v1.28+) |
| 0x0008 | Command Mode Guard (v1.28+) |

### SS -- Services Bitmap

| Bit  | Service |
| ---- | --- |
| 0x80 | Device Information |
| 0x40 | UART Transparent |
| 0x20 | Beacon |

**Warning:** Issuing `SS` removes all custom-defined services. Use before `PS`/`PC`.

### TX Power Levels

| Value | Power |
| ----- | --- |
| 0 | 0 dBm |
| 1 | -5 dBm  |
| 2 | -10 dBm |
| 3 | -15 dBm |
| 4 | -20 dBm |
| 5 | -25 dBm |

### Action Commands

| Command | Description |
| --- | --- |
| `$$$` | Enter Command mode |
| `---\r` | Exit to Data mode |
| `A[,<int>,<to>]`  | Start advertisement |
| `Y` | Stop advertisement |
| `F[,<int>,<win>]` | Start scan |
| `X` | Stop scan |
| `C,<0/1>,<addr>`  | Connect (0=public, 1=random) |
| `K,1` | Disconnect |
| `B` | Bond current connection |
| `R,1` | Reboot |
| `D` | Dump device info |
| `V` | Firmware version |
| `U,<1-8/Z>` | Remove bonding |

### Service Configuration

| Command | Description |
| --- | --- |
| `PS,<UUID>` | Define service UUID |
| `PC,<UUID>,<prop>,<size>` | Add characteristic |
| `PZ` | Clear all private services (needs reboot) |

**Characteristic Properties:**

| Bit  | Property |
| ---- | --- |
| 0x02 | Read |
| 0x04 | Write without response |
| 0x08 | Write |
| 0x10 | Notify |
| 0x20 | Indicate |

Common: `0x02`=Read, `0x0A`=Read+Write, `0x1A`=Read+Write+Notify

### Characteristic Access

| Command | Description |
| --- | --- |
| `SHR,<handle>` | Read local characteristic |
| `SHW,<handle>,<data>` | Write local characteristic (triggers notify) |
| `CHR,<handle>` | Read remote characteristic |
| `CHW,<handle>,<data>` | Write remote characteristic |
| `CI` | Init client role (service discovery) |

---

## Status Events

Wrapped in delimiters (default `%`):

| Event | Description |
| --- | --- |
| `%REBOOT%` | Reboot complete |
| `%CONNECT,<0-1>,<Addr>%` | Connected |
| `%DISCONNECT%` | Disconnected |
| `%STREAM_OPEN%` | Transparent UART pipe ready |
| `%SECURED%` | Link secured |
| `%BONDED%` | Bonding complete |
| `%WV,<hdl>,<hex>%` | Write received for characteristic |
| `%RV,<hdl>,<hex>%` | Read value for characteristic |
| `%NOTI,<hdl>,<hex>%` | Notification received (client) |
| `%CONN_PARAM,<I>,<L>,<T>%` | Connection params updated |
| `%ERR_SEC%` | Security failed |

---

## Transparent UART Service

- **Service UUID:** `49535343-FE7D-4AE5-8FA9-9FAFD205E455`
- **TX characteristic:** `49535343-1E4D-4BD9-BA61-23C647249616` (Notify, Write)
- **RX characteristic:** `49535343-8841-43F4-A8D4-ECBE34729BB3` (Write)
- Max data rate: ~10 kBps

---

## RN4871 Pinout (16 pins)

| Pin | Name | Description |
| --- | --- | --- |
| 1 | BT_RF | Antenna |
| 2 | GND | Ground |
| 3 | P1_2 | GPIO / I2C_SCL |
| 4 | P1_3 | GPIO / I2C_SDA |
| 7 | UART_RX | Data input -> connect to MCU TX |
| 8 | UART_TX | Data output -> connect to MCU RX |
| 9 | P3_6 | UART_RTS (default) |
| 10  | RST_N | Reset, active-low, internal pull-high |
| 11  | P0_0 | UART_CTS (default) |
| 14  | VBAT | Supply: 1.9-3.6V |
| 16  | P2_0 | Mode: high=App, low=Test |

---

## Electrical Characteristics

| Parameter | Min | Max  | Unit |
| --- | --- | ---- | ---- |
| Supply (VBAT) | 1.9 | 3.6  | V |
| TX peak (0 dBm) | --  | 13 | mA |
| RX peak | --  | 13 | mA |
| Standby | 1.9 | 2.9  | uA |
| Advertising @ 100 ms | --  | 0.23 | mA |

### I/O Levels

| Parameter | Value |
| --- | --- |
| VIL | 0 to 0.3\*VDD |
| VIH | 0.7\*VDD to VDD |

---

## Timing

| Event | Time |
| --- | --- |
| Power-on to UART ready | 46 ms |
| Full initialization | 68 ms |
| Recommended wait | 100 ms |
| Command mode entry delay | 100 ms before first `$`  |
| Low-power wake delay | 5 ms after RX_IND low |
| Reset pulse minimum | 63 ns (recommend > 1 ms) |

---

## Initialization Sequence (Peripheral with Transparent UART)

```
$$$                      -> CMD>
SF,1\r                   -> (reboots, %REBOOT%)
$$$                      -> CMD>
SN,MeteoStation\r        -> AOK
SS,C0\r                  -> AOK   // Device Info + Transparent UART
SA,2\r                   -> AOK   // No Input No Output
SR,4000\r                -> AOK   // No prompt (for MCU parsing)
R,1\r                    -> %REBOOT%
```

## Reference Circuit (RN4871)

```
MCU TX   --> RN4871 UART_RX (pin 7)
MCU RX   <-- RN4871 UART_TX (pin 8)
MCU GPIO --> RN4871 RST_N   (pin 10)
3.3V     --> RN4871 VBAT    (pin 14)
GND      --> RN4871 GND     (pins 2, 13)
```

Recommended: 4.7k pull-up + 1 uF cap on RST_N, 10 uF bulk cap on VBAT.

If using flow control (SR,8000):

```
MCU CTS <-- RN4871 P3_6/RTS (pin 9)
MCU RTS --> RN4871 P0_0/CTS (pin 11)
```

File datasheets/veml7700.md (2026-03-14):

# VEML7700 -- High Accuracy Ambient Light Sensor

**Manufacturer:** Vishay Semiconductors
**Datasheet Rev:** 1.8, 28-Nov-2024

## Device Overview

16-bit ambient light sensor in a 6.8 x 2.35 x 3.0 mm package. Integrates photodiode, amplifier, 16-bit ADC, and I2C interface. Two channels: ALS (photopic response) and WHITE (broader spectral sensitivity).

- **Range:** 0 to ~140,000 lx
- **Best resolution:** 0.0042 lx/count
- **Flicker rejection:** 100 Hz and 120 Hz
- **Shutdown current:** 0.5 uA typ

## Pin Descriptions

| Pin | Name | Function |
| --- | ---- | --- |
| 1 | SCL  | I2C clock |
| 2 | VDD  | Supply (2.5-3.6V) |
| 3 | GND  | Ground |
| 4 | SDA  | I2C data |

## Electrical Characteristics

| Parameter | Min | Typ | Max | Unit |
| --- | --- | --- | --- | ---- |
| VDD | 2.5 | 3.3 | 3.6 | V |
| Shutdown current | --  | 0.5 | --  | uA |
| Active current (PSM off) | --  | 45  | --  | uA |
| I2C bus voltage | 1.7 | --  | 3.6 | V |
| I2C clock rate | 10  | --  | 400 | kHz  |

## I2C Protocol

- **Address:** 0x10 (7-bit, fixed, not configurable)
- All registers 16-bit, LSB first
- Pull-ups: > 1 kOhm, recommended 2.2-4.7 kOhm
- No interrupt pin -- polling required

## Register Map

| Cmd  | Name | R/W | Description |
| ---- | --- | --- | --- |
| 0x00 | ALS_CONF_0 | R/W | Configuration (gain, integration time, interrupt, shutdown) |
| 0x01 | ALS_WH | R/W | High threshold (16-bit) |
| 0x02 | ALS_WL | R/W | Low threshold (16-bit) |
| 0x03 | Power Saving | R/W | PSM mode and enable |
| 0x04 | ALS | R | Ambient light output (16-bit) |
| 0x05 | WHITE | R | White channel output (16-bit) |
| 0x06 | ALS_INT | R | Interrupt status (bit 15: low, bit 14: high) |
| 0x07 | ID | R | Device ID (low byte = 0x81) |

## Configuration Register (0x00)

| Bits  | Field | Description |
| ----- | --- | --- |
| 12:11 | ALS_GAIN | 00=x1, 01=x2, 10=x1/8, 11=x1/4 |
| 9:6 | ALS_IT | Integration time (see below) |
| 5:4 | ALS_PERS | Persistence (00=1, 01=2, 10=4, 11=8) |
| 1 | ALS_INT_EN | 0=disable, 1=enable interrupt |
| 0 | ALS_SD | 0=power on, 1=shutdown |

**Default: 0x0001** (shutdown mode).

### Integration Time (bits 9:6)

| Value | Time |
| ----- | --- |
| 1100  | 25 ms  |
| 1000  | 50 ms  |
| 0000  | 100 ms |
| 0001  | 200 ms |
| 0010  | 400 ms |
| 0011  | 800 ms |

### Power Saving Mode (register 0x03)

| Bits | Field  | Description |
| ---- | --- | --- |
| 2:1  | PSM | 00=mode 1, 01=mode 2, 10=mode 3, 11=mode 4 |
| 0 | PSM_EN | 0=disable (continuous), 1=enable |

## Lux Calculation

```
Lux = ALS_raw * resolution
```

### Resolution Table

| Gain | Integration Time | Resolution (lx/count) |
| ---- | --- | --- |
| x2 | 800 ms | 0.0042 |
| x2 | 400 ms | 0.0084 |
| x2 | 200 ms | 0.0168 |
| x2 | 100 ms | 0.0336 |
| x1 | 100 ms | 0.0672 |
| x1/4 | 100 ms | 0.2688 |
| x1/8 | 100 ms | 0.5376 |
| x1/8 | 25 ms | 2.1504 |

General formula: `resolution = 0.0042 * (800 / ALS_IT_ms) * (2 / gain_multiplier)`

### Nonlinearity Correction (above ~1000 lx)

```
lux_corrected = 6.0135e-13 * lux^4 - 9.3924e-09 * lux^3 + 8.1488e-05 * lux^2 + 1.0023 * lux
```

## Initialization and Reading

1. Write 0x00 with desired config (clear ALS_SD to power on)
2. (Optional) Configure PSM in register 0x03
3. Wait one integration period
4. Read register 0x04 for ALS data
5. Convert to lux using resolution table
6. Apply correction polynomial if > 1000 lx

### Verify communication: read register 0x07, low byte should be 0x81

## Driver Notes

- Powers up in shutdown mode -- must clear ALS_SD
- After changing gain/integration time, discard first reading
- Fixed I2C address 0x10 -- no configuration available
- No physical interrupt pin despite register support

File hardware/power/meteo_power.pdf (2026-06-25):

1 | 2 | 3 | 4 | 5 | 6 | 7 | 8
1 | 2 | 3 | 4 | 5 | 6 | 7 | 8

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
Size: A3 | Rev: 1.0
KiCad E.D.A. 10.0.4 | Id: 1/1 | F Date:

## Title: Meteo Station Power

File: meteo_power.kicad_sch

### Sheet: /

C2

100uF 1
2
3
4 U2 MT3608 -> 5.0V | D1

1N5817

1
2
3
4

5 U3

ESP32-H2-DevKitM-1

1
2
3
4
5

6 U7

INA219 0x41 (BATT) | R3
4.75k | R4

4.75k C1

22uF BT1

1S LiPo 3.7V 10Ah 1
2
3
4
5

6 U6

INA219 0x40 (PV) | C3

10uF 1
2
3

4 U8 BME280 0x76

1
2
3

4 U9

VEML7700 0x10

1
2
3
4 U1 CN3791 12V MPPT | C6

100nF 1
2
3
4 U4 BMP388 0x77 | C4
10uF | 1
2
3

4 U5 MLX90614 0x5A C5

100nF

1
2

J1 PV-12W 12V 1A

# V3V3 GND

V3V3

SCL GND

V3V3

SDA

V3V3

V5

SCL SDA GND

V3V3

V5 | BOOST5V GND

BOOST5V GND

VLOAD

SDA GND

V3V3

SCL | V3V3 GND

SCL SDA GND

V3V3

V3V3 GND

V5 GND

V5 GND

SCL SCL SDA

GND

V3V3 GND

SDA

GND

V3V3

SCL V3V3 GND

SCL SDA SOLAR+

VLOAD

SOLAR_CHG

SOLAR_CHG

GND

VBAT GND

VLOAD

GND

GND

VBAT

SOLAR+

VBAT SDA Rule: a 100nF sits right at each chip; bulk caps go where current steps (boost out, radio, regulator).

U8 BME280 & U9 VEML7700 are breakout modules (onboard decoupling); only the bare MLX90614 needs its external 100nF.

Both INA219 on I2C0 (VCC=3V3, 0.1ohm onboard shunt). GPIO2/ADC1_CH1 now a free spare; battery V comes from U7.

U7 INA219 0x41: high-side on the battery->boost feed = load current + battery voltage (Vbus).

U6 INA219 0x40: high-side on the PV feed = harvest current + panel voltage.

### C5 100nF - across BMP388 VCC-GND, hard against the chip's pins

C4 10uF | - bulk on the 3V3 rail, at the DevKit 3V3 pin
C3 10uF | - beside C2 at the DevKit 5V pin

### C2 100uF - bulk on the 5V rail, at the DevKit 5V pin

### C1 22uF - bulk at the MT3608 input (VLOAD, right at boost VIN, after the U7 shunt)

## Capacitor placement (physical):

### C6 100nF - across MLX90614 VCC-GND, hard against the chip's pins

D1 (1N5817): MT3608 5V -> DevKit 5V pin; isolates the boost so USB VBUS wins when flashing (no back-feed).

PV-12W -> [U6 INA219] -> CN3791 12V MPPT -> 1S LiPo -> [U7 INA219] -> MT3608 (5.0V) -> DevKit 5V pin.

# Meteo Station — Power Subsystem (generated)

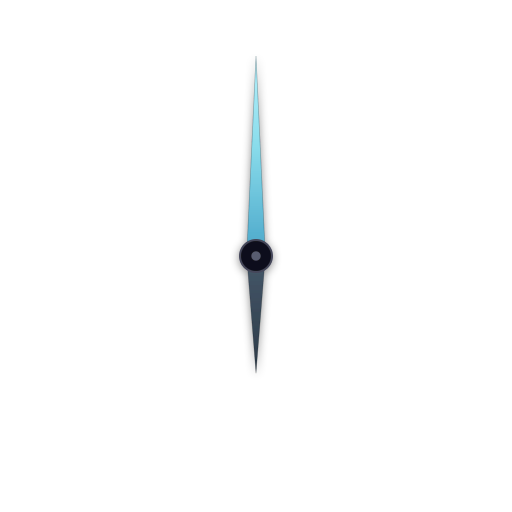
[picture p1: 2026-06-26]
crates/meteo-tui/assets/compass/compass-needle.png

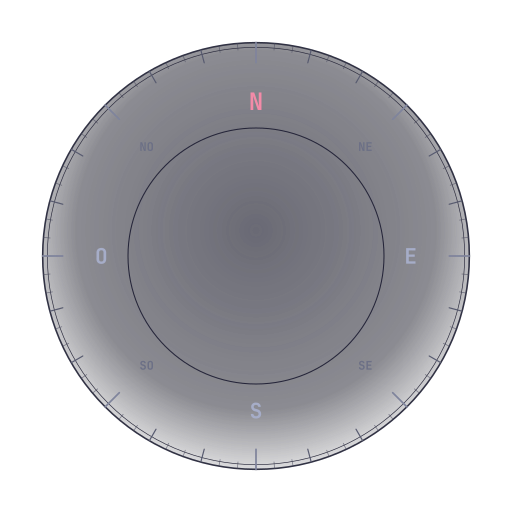
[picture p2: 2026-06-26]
crates/meteo-tui/assets/compass/compass-dial.png

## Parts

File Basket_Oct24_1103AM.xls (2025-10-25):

SHOPPING BASKET
This is not an invoice
24-Oct-25 11:03:57
 | Mouser No | Mfr. No | Manufacturer | Customer No | Description | RoHS | Lifecycle | Order Qty. | Price (EUR) | Ext.: (EUR)
1 | 80-C320C106K3R5TA | C320C106K3R5TA | KEMET |  | Multilayer Ceramic Capacitors MLCC - Leaded 25V 10uF X7R 10% LS=2.54mm | RoHS Compliant |  | 5 | 2,80 € | 14,00 €
2 | 667-ECA-1CM101I | ECA-1CM101I | Panasonic |  | Aluminium Electrolytic Capacitors - Radial Leaded 100UF 16V ELECT M RADIAL | RoHS Compliant |  | 1 | 0,086 € | 0,09 €
3 | 80-C320C104K5R | C320C104K5R5TA | KEMET |  | Multilayer Ceramic Capacitors MLCC - Leaded 50V 0.1uF X7R 10% LS=2.54mm | RoHS Compliant |  | 15 | 0,208 € | 3,12 €
4 | 603-MFR-25FBF52-36K | MFR-25FBF52-36K | YAGEO |  | Metal Film Resistors - Through Hole 36K OHM 1/4W 1% | RoHS Compliant |  | 1 | 0,086 € | 0,09 €
5 | 603-MFR-25FBF52-5K1 | MFR-25FBF52-5K1 | YAGEO |  | Metal Film Resistors - Through Hole 5.1K OHM 1/4W 1% | RoHS Compliant |  | 10 | 0,034 € | 0,34 €
6 | 603-MFR-25FBF52-4K75 | MFR-25FBF52-4K75 | YAGEO |  | Metal Film Resistors - Through Hole 4.75K OHM 1/4W 1% | RoHS Compliant |  | 10 | 0,034 € | 0,34 €
7 | 603-MFR-25FBF52-100K | MFR-25FBF52-100K | YAGEO |  | Metal Film Resistors - Through Hole 100K OHM 1/4W 1% | RoHS Compliant |  | 10 | 0,034 € | 0,34 €
8 | 603-MFR-25FBF52-10K | MFR-25FBF52-10K | YAGEO |  | Metal Film Resistors - Through Hole 10K OHM 1/4W 1% | RoHS Compliant |  | 30 | 0,022 € | 0,66 €
9 | 542-RL875S-220L-RC | RL875S-220L-RC | Bourns |  | RF inductors - Leaded 22uH 15% | RoHS Compliant |  | 1 | 1,41 € | 1,41 €
10 | 588-13FR100E | 13FR100E | Ohmite |  | Current Sense Resistors - Through Hole 3watts 0.1OHMS 1% | RoHS Compliant |  | 1 | 2,40 € | 2,40 €
11 | 621-1N5817 | 1N5817-T | Diodes Incorporated |  | Schottky Diodes & Rectifiers Vr/20V Io/1A T/R | RoHS Compliant By Exemption |  | 1 | 0,189 € | 0,19 €
12 | 81-RCER71E226MWK1H3B | RCER71E226MWK1H03B | Murata |  | Multilayer Ceramic Capacitors MLCC - Leaded 22UF 25V 20% 5.0MM | RoHS Compliant |  | 3 | 1,63 € | 4,89 €
13 | 81-RCEC71H226MWK1H3B | RCEC71H226MWK1H03B | Murata |  | Multilayer Ceramic Capacitors MLCC - Leaded 22UF 50V 20% 7.5MM | RoHS Compliant |  | 2 | 1,70 € | 3,40 €
By submitting your order you agree to these terms and conditions. (https://www.mouser.fr/saleterms) |  |  |  |  |  |  |  |  | Merchandise: | 31,27 €
Prices are reflected at the date and time shown. |  |  |  |  |  |  |  |  | Delivery Charge: | 20,00 €

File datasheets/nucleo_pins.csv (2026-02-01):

Connector | Pin | Pin name | Signal name | STM32H7 pin | MCU function
CN7 | 1 | D16 | I2S_A_MCK | PC6 | I2S_2
CN7 | 2 | D15 | I2C_A_SCL | PB8 | I2C_1_SCL
CN7 | 3 | D17 | I2S_A_SD | PB15 | I2S_2
CN7 | 4 | D14 | I2C_A_SDA | PB9 | I2C_1_SDA
CN7 | 5 | D18 | I2S_A_CK | PB13 | I2S_2
CN7 | 6 | VREFP | VREFP | - | VDDA/VREFP
CN7 | 7 | D19 | I2S_A_WS | PB12 | I2S_2
CN7 | 8 | GND | GND | - | -
CN7 | 9 | D20 | I2S_B_WS | PA15 | I2S_3
CN7 | 10 | D13 | SPI_A_SCK | PA5 | SPI1_SCK
CN7 | 11 | D21 | I2S_B_MCK | PC7 | I2S_3
CN7 | 12 | D12 | SPI_A_MISO | PA6 | SPI1_MISO
CN7 | 13 | D22 | I2S_B_SD/SPI_B_MOSI | PB5 | I2S_3/SPI3
CN7 | 14 | D11 | SPI_A_MOSI/TIM_E_PWM1 | PB5 | SPI1_MOSI/TIM3_CH2
CN7 | 15 | D23 | I2S_B_CK/SPI_B_SCK | PB3 | I2S_3/SPI3
CN7 | 16 | D10 | SPI_A_CS/TIM_B_PWM3 | PD14 | SPI1_CS/TIM4_CH3
CN7 | 17 | D24 | SPI_B_NSS | PA4 | SPI3
CN7 | 18 | D9 | TIM_B_PWM2 | PD15 | TIM4_CH4
CN7 | 19 | D25 | SPI_B_MISO | PB4 | SPI3
CN7 | 20 | D8 | I/O | PF3 | -
CN8 | 1 | NC | NC | - | -
CN8 | 2 | D43 | SDMMC_D0 | PC8 | SDMMC
CN8 | 3 | IOREF | IOREF | - | 3.3 V reference
CN8 | 4 | D44 | SDMMC_D1/I2S_A_CKIN | PC9 | SDMMC/I2S_CKIN
CN8 | 5 | NRST | NRST | NRST | RESET
CN8 | 6 | D45 | SDMMC_D2 | PC10 | SDMMC
CN8 | 7 | 3V3 | 3V3 | - | 3.3 V input/output
CN8 | 8 | D46 | SDMMC_D3 | PC11 | SDMMC
CN8 | 9 | 5V | 5V | - | 5 V output
CN8 | 10 | D47 | SDMMC_CK | PC12 | SDMMC
CN8 | 11 | GND | GND | - | ground
CN8 | 12 | D48 | SDMMC_CMD | PD2 | SDMMC
CN8 | 13 | GND | GND | - | ground
CN8 | 14 | D49 | I/O | PG2 | -
CN8 | 15 | VIN | VIN | - | Power input
CN8 | 16 | D50 | I/O | PG3 | -
CN9 | 1 | A0 | ADC | PA3 | ADC12_INP15
CN9 | 2 | D51 | USART_B_SCLK | PD7 | USART_2
CN9 | 3 | A1 | ADC | PC0 | ADC123_INP10
CN9 | 4 | D52 | USART_B_RX | PD6 | USART_2
CN9 | 5 | A2 | ADC | PC3 | ADC12_INP13
CN9 | 6 | D53 | USART_B_TX | PD5 | USART_2
CN9 | 7 | A3 | ADC | PB1 | ADC12_INP5
CN9 | 8 | D54 | USART_B_RTS | PD4 | USART_2
CN9 | 9 | A4 | ADC | PC2/PB9 | ADC123_INP12/I2C1_SDA
CN9 | 10 | D55 | USART_B_CTS | PD3 | USART_2
CN9 | 11 | A5 | ADC | PF10/PB8 | ADC3_INP6/I2C1_SCL
CN9 | 12 | GND | GND | - | -
CN9 | 13 | D72 | COMP1_INP | PB2 | COMP1_INP
CN9 | 14 | D56 | SAI_A_MCLK | PE2 | SAI_1_A
CN9 | 15 | D71 | COMP2_INP | PE9 | COMP2_INP
CN9 | 16 | D57 | SAI_A_FS | PE4 | SAI_1_A
CN9 | 17 | D70 | I2C_B_SMBA | PF2 | I2C2
CN9 | 18 | D58 | SAI_A_SCK | PE5 | SAI_1_A
CN9 | 19 | D69 | I2C_B_SCL | PF1 | I2C2
CN9 | 20 | D59 | SAI_A_SD | PE6 | SAI_1_A
CN9 | 21 | D68 | I2C_B_SDA | PF0 | I2C2
CN9 | 22 | D60 | SAI_B_SD | PE3 | SAI_1_B
CN9 | 23 | GND | GND | - | -
CN9 | 24 | D61 | SAI_B_SCK | PF8 | SAI_1_B
CN9 | 25 | D67 | CAN_RX | PD0 | CAN_1
CN9 | 26 | D62 | SAI_B_MCLK | PF7 | SAI_1_B
CN9 | 27 | D66 | CAN_TX | PD1 | CAN_1
CN9 | 28 | D63 | SAI_B_FS | PF9 | SAI_1_B
CN9 | 29 | D65 | I/O | PG0 | -
CN9 | 30 | D64 | I/O | PG1 | -
CN10 | 1 | AVDD | VDDA | - | Analog VDD
CN10 | 2 | D7 | I/O | PG12 | I/O
CN10 | 3 | AGND | AGND | - | Analog GND
CN10 | 4 | D6 | TIMER_A_PWM1 | PE9 | TIM1_CH1
CN10 | 5 | GND | GND | - | GND
CN10 | 6 | D5 | TIMER_A_PWM2 | PE11 | TIM1_CH2
CN10 | 7 | A6 | ADC_A_IN | PF4 | ADC3_INP9
CN10 | 8 | D4 | I/O | PE14 | I/O
CN10 | 9 | A7 | ADC_B_IN | PF5 | ADC3_INP4
CN10 | 10 | D3 | TIMER_A_PWM3 | PE13 | TIM1_CH3
CN10 | 11 | A8 | ADC_C_IN | PF6 | ADC3_INP8
CN10 | 12 | D2 | I/O | PG14 | I/O
CN10 | 13 | D26 | QSPI_CS | PG6 | QSPI1_NCS
CN10 | 14 | D1 | USART_A_TX | PB6 | LPUART1
CN10 | 15 | D27 | QSPI_CLK | PB2 | QSPI1_CLK
CN10 | 16 | D0 | USART_A_RX | PB7 | LPUART1
CN10 | 17 | GND | GND | - | GND
CN10 | 18 | D42 | TIMER_A_PWM1N | PE8 | TIM1_CH1N
CN10 | 19 | D28 | QSPI_BK1_IO3 | PD13 | QSPI1_IO
CN10 | 20 | D41 | TIMER_A_ETR | PE7 | TIM1_ETR
CN10 | 21 | D29 | QSPI_BK1_IO1 | PD12 | QSPI1_IO
CN10 | 22 | GND | GND | - | GND
CN10 | 23 | D30 | QSPI_BK1_IO0 | PD11 | QSPI1_IO
CN10 | 24 | D40 | TIMER_A_PWM2N | PE10 | TIM1_CH2N
CN10 | 25 | D31 | QSPI_BK1_IO2 | PE2 | QSPI1_IO
CN10 | 26 | D39 | TIMER_A_PWM3N | PE12 | TIM1_CH3N
CN10 | 27 | GND | - | - | -
CN10 | 28 | D38 | TIMER_A_BKIN2 | PE6 | TIM1_BKIN2
CN10 | 29 | D32 | TIM_C_PWM1 | PA0 | TIM2_CH1
CN10 | 30 | D37 | TIMER_A_BKIN1 | PE15 | TIM1_BKIN1
CN10 | 31 | D33 | TIM_D_PWM1 | PB0 | TIM3_CH3
CN10 | 32 | D36 | TIMER_C_PWM2 | PB10 | TIM2_CH3
CN10 | 33 | D34 | TIM_B_ETR | PE0 | TIM4_ETR
CN10 | 34 | D35 | TIMER_C_PWM3 | PB11 | TIM2_CH4

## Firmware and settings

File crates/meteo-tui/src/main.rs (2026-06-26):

//! meteo-tui: terminal dashboard for the `MeteoStation` BLE peripheral.
#![allow(
    clippy::std_instead_of_core,
    clippy::std_instead_of_alloc,
    clippy::alloc_instead_of_core,
    reason = "meteo-tui is a host std binary; core/alloc-first lints do not apply"
)]

mod app;
mod ble;
mod image_render;
mod model;
mod plot;
mod theme;
mod ui;

use std::time::Duration;

use clap::Parser;

/// Marker style for history charts.
#[derive(Clone, Copy, Debug, Default, clap::ValueEnum)]
enum MarkerArg {
    /// Individual Braille dots — one glyph per sample (sparse).
    #[default]
    Dots,
    /// Braille line segments connecting consecutive samples.
    Line,
}

impl From<MarkerArg> for plot::MarkerStyle {
    fn from(m: MarkerArg) -> Self {
        match m {
            MarkerArg::Dots => Self::Dots,
            MarkerArg::Line => Self::Line,
        }
    }
}

/// History-chart smoothing strength. Maps to a Gaussian kernel width (σ, in
/// samples) applied to each trace's main line before rasterizing; the gust
/// envelope and rain bars are never smoothed.
#[derive(Clone, Copy, Debug, Default, clap::ValueEnum)]
enum SmoothingArg {
    /// No smoothing — raw 1 Hz samples.
    Off,
    /// σ ≈ 2 samples — just takes the jitter off.
    Subtle,
    /// σ ≈ 3.5 samples — clearly smoother, real features still read (default).
    #[default]
    Medium,
    /// σ ≈ 7 samples — very smooth / trend-like.
    Strong,
}

impl SmoothingArg {
    /// Gaussian kernel width (σ, in samples). `0.0` disables smoothing.
    const fn sigma(self) -> f64 {
        match self {
            Self::Off => 0.0,
            Self::Subtle => 2.0,
            Self::Medium => 3.5,
            Self::Strong => 7.0,
        }
    }
}

/// Terminal image-protocol selection. `Auto` keeps `ratatui-image`'s terminal
/// query (`Kitty` on `WezTerm`); the others force a specific protocol for
/// terminals whose auto-detected protocol misbehaves (many simultaneous images).
#[derive(Clone, Copy, Debug, Default, clap::ValueEnum)]
enum ProtocolArg {
    /// Auto-detect via terminal query (default).
    #[default]
    Auto,
    /// Kitty graphics protocol.
    Kitty,
    /// Sixel.
    Sixel,
    /// iTerm2 inline images.
    Iterm2,
    /// Unicode half-blocks (works everywhere; chunky).
    Halfblocks,
}

#[derive(Parser)]
#[command(version, about = "MeteoStation live BLE dashboard")]
struct Cli {
    /// Station BLE address (`BlueZ` display order). Defaults to the firmware address.
    #[arg(long, default_value = "F0:CA:FE:00:00:01")]
    address: String,

    /// Trace marker style for history charts (dots or line).
    #[arg(long, value_enum, default_value_t = MarkerArg::Dots)]
    marker_style: MarkerArg,

    /// Draw faint gridlines at 25 / 50 / 75 % in history charts.
    #[arg(long, default_value_t = true, action = clap::ArgAction::Set)]
    show_grid: bool,

    /// Show the 60-second heading trail in the wind compass.
    /// Parsed but no longer affects rendering; the image compass replaced the
    /// canvas trail and does not currently render a heading history.
    #[arg(long, default_value_t = true, action = clap::ArgAction::Set)]
    gust_trail: bool,

    /// Draw the gradient area fill under history traces (dossier look). Off by
    /// default — in a braille terminal the fill makes spiky signals unreadable.
    #[arg(long, default_value_t = false, action = clap::ArgAction::Set)]
    fill: bool,

    /// Override the terminal image protocol (auto / kitty / sixel / iterm2 /
    /// halfblocks). Use when the auto-detected protocol fails to show charts.
    #[arg(long, value_enum, default_value_t = ProtocolArg::Auto)]
    image_protocol: ProtocolArg,

    /// History-chart trace smoothing (off / subtle / medium / strong). A
    /// centered Gaussian moving average; gust envelope and rain bars stay raw.
    #[arg(long, value_enum, default_value_t = SmoothingArg::Medium)]
    smoothing: SmoothingArg,
}

#[tokio::main]
async fn main() -> anyhow::Result<()> {
    let cli = Cli::parse();
    let addr: bluer::Address = cli.address.parse()?;
    let options = ui::Options {
        marker_style: cli.marker_style.into(),
        show_grid: cli.show_grid,
        gust_trail: cli.gust_trail,
        fill: cli.fill,
        smooth_sigma: cli.smoothing.sigma(),
    };

    // Query terminal graphics protocol capabilities BEFORE entering alternate
    // screen — the query uses stdio which is unavailable inside alternate mode.
    let mut picker = ratatui_image::picker::Picker::from_query_stdio()
        .unwrap_or_else(|_| ratatui_image::picker::Picker::halfblocks());
    let forced = match cli.image_protocol {
        ProtocolArg::Auto => None,
        ProtocolArg::Kitty => Some(ratatui_image::picker::ProtocolType::Kitty),
        ProtocolArg::Sixel => Some(ratatui_image::picker::ProtocolType::Sixel),
        ProtocolArg::Iterm2 => Some(ratatui_image::picker::ProtocolType::Iterm2),
        ProtocolArg::Halfblocks => Some(ratatui_image::picker::ProtocolType::Halfblocks),
    };
    if let Some(pt) = forced {
        picker.set_protocol_type(pt);
    }
    let mut images = image_render::Images::new(picker);

    // ratatui::init() enables raw mode + alternate screen AND installs a panic
    // hook that restores the terminal on panic. ratatui::restore() undoes it.
    let mut terminal: ratatui::DefaultTerminal = ratatui::init();
    let res = run_app(&mut terminal, addr, options, &mut images).await;
    ratatui::restore();
    res
}

async fn run_app(
    terminal: &mut ratatui::DefaultTerminal,
    addr: bluer::Address,
    options: ui::Options,
    // Image-protocol caches (charts + compass); image rebuilds are gated on data
    // version inside Images so unchanged-data redraws at 10 Hz are cheap.
    images: &mut image_render::Images,
) -> anyhow::Result<()> {
    use futures::StreamExt as _;

    let (tx, mut rx) = tokio::sync::mpsc::channel(64);
    tokio::spawn(crate::ble::run(tx, addr));

    let mut input = crossterm::event::EventStream::new();
    // Display cadence: 10 Hz, SOLELY to advance the displayed wall clock and
    // animate the pulsing dot. This is a display cadence, NOT a readiness
    // sleep — you cannot observe the wall clock advancing except via a timer.
    // All DATA-driven redraws happen on BLE/input events below; this tick
    // only keeps the clock and pulse animation live.
    let mut clock = tokio::time::interval(Duration::from_millis(100));

    let mut app = crate::app::AppState::new(std::time::Instant::now());
    let started = std::time::Instant::now();
    loop {
        tokio::select! {
            Some(ev) = rx.recv() => app.apply(ev, std::time::Instant::now()),
            Some(Ok(term_ev)) = input.next() => {
                if should_quit(&term_ev) { break; }
            }
            _ = clock.tick() => {}
        }
        let pulse = pulse_intensity(started.elapsed());
        terminal.draw(|f| {
            crate::ui::render(
                f,
                &mut app,
                std::time::Instant::now(),
                options,
                pulse,
                images,
            );
        })?;
    }
    Ok(())
}

/// 1.6 s triangle wave in [0.35,1.0] for the « En direct » dot. Pure.
fn pulse_intensity(elapsed: Duration) -> f64 {
    const PERIOD: f64 = 1.6;
    let phase = (elapsed.as_secs_f64() % PERIOD) / PERIOD; // 0..1
    let tri = 1.0 - phase.mul_add(2.0, -1.0).abs(); // 0..1..0
    0.35 + tri * 0.65 // 0.35..1.0
}

/// Pure: quit on 'q', Esc, or Ctrl-C. Testable (no I/O).
const fn should_quit(ev: &crossterm::event::Event) -> bool {
    use crossterm::event::{Event, KeyCode, KeyEvent, KeyModifiers};
    matches!(
        ev,
        Event::Key(
            KeyEvent {
                code: KeyCode::Char('q') | KeyCode::Esc,
                ..
            } | KeyEvent {
                code: KeyCode::Char('c'),
                modifiers: KeyModifiers::CONTROL,
                ..
            }
        )
    )
}

// grcov exclude start
#[expect(clippy::panic_in_result_fn, reason = "test module")]
#[allow(
    clippy::unnecessary_wraps,
    reason = "TestResult is the standard test pattern"
)]
#[cfg(test)]
mod tests {
    use core::{error, result};

    use crossterm::event::{Event, KeyCode, KeyEvent, KeyModifiers};
    use test_log::test;

    use super::*;

    type TestResult = result::Result<(), Box<dyn error::Error>>;

    #[test]
    fn should_quit_on_q_key() -> TestResult {
        // Given
        let ev = Event::Key(KeyEvent::new(KeyCode::Char('q'), KeyModifiers::NONE));

        // When
        let result = should_quit(&ev);

        // Then
        assert!(result);
        Ok(())
    }

    #[test]
    fn should_quit_on_esc() -> TestResult {
        // Given
        let ev = Event::Key(KeyEvent::new(KeyCode::Esc, KeyModifiers::NONE));

        // When
        let result = should_quit(&ev);

        // Then
        assert!(result);
        Ok(())
    }

    #[test]
    fn should_quit_on_ctrl_c() -> TestResult {
        // Given
        let ev = Event::Key(KeyEvent::new(KeyCode::Char('c'), KeyModifiers::CONTROL));

        // When
        let result = should_quit(&ev);

        // Then
        assert!(result);
        Ok(())
    }

    #[test]
    fn should_not_quit_on_other_key() -> TestResult {
        // Given
        let ev = Event::Key(KeyEvent::new(KeyCode::Char('x'), KeyModifiers::NONE));

        // When
        let result = should_quit(&ev);

        // Then
        assert!(!result);
        Ok(())
    }

    #[test]
    fn pulse_intensity_bounds() -> TestResult {
        // Given / When
        let at_zero = pulse_intensity(Duration::ZERO);
        let at_800ms = pulse_intensity(Duration::from_millis(800));

        // Then — both are within [0.35, 1.0] and they differ across the cycle
        assert!(
            (0.35..=1.0).contains(&at_zero),
            "pulse at 0ms should be in [0.35, 1.0]; got {at_zero}"
        );
        assert!(
            (0.35..=1.0).contains(&at_800ms),
            "pulse at 800ms should be in [0.35, 1.0]; got {at_800ms}"
        );
        assert!(
            (at_zero - at_800ms).abs() > f64::EPSILON,
            "pulse at 0ms ({at_zero}) and 800ms ({at_800ms}) should differ"
        );

        Ok(())
    }
}
// grcov exclude stop

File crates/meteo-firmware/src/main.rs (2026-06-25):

#![no_std]
#![no_main]
#![expect(
    clippy::expect_used,
    reason = "firmware init: no recovery from a failed peripheral init or spawn"
)]
#![expect(
    clippy::missing_asserts_for_indexing,
    reason = "false positives from defmt macro expansion"
)]
#![expect(
    clippy::future_not_send,
    reason = "Embassy/esp-rtos executor is single-threaded; Spawner and task futures are !Send by design"
)]

mod aggregator;
mod anemometer;
mod ble;
mod bme;
mod bmp;
mod bus;
mod config;
mod ina;
mod mlx;
mod rain;
mod vane;
mod veml;
mod watchdog;

use defmt::info;
use embassy_embedded_hal::shared_bus::asynch::i2c::I2cDevice;
use embassy_executor::Spawner;
use embassy_sync::mutex::Mutex;
use embassy_time::{Duration, Timer};
use esp_bootloader_esp_idf::partitions::{
    DataPartitionSubType, PartitionType, read_partition_table,
};
use esp_hal::clock::CpuClock;
use esp_hal::gpio::{Input, InputConfig, Level, Output, OutputConfig, Pull};
use esp_hal::i2c::master::{Config as I2cConfig, I2c};
use esp_hal::interrupt::software::SoftwareInterruptControl;
use esp_hal::rtc_cntl::Rtc;
use esp_hal::time::Rate;
use esp_hal::timer::timg::TimerGroup;
use esp_radio::ble::Config as BleConfig;
use esp_radio::ble::controller::BleConnector;
use esp_storage::FlashStorage;
use {esp_backtrace as _, esp_println as _};

use crate::bus::{I2C_BUS, SharedI2c};

// The ESP-IDF second-stage bootloader (espflash v4) needs this app descriptor in
// the image to boot it.
esp_bootloader_esp_idf::esp_app_desc!();

/// BMP388 I2C address (SDO tied high). 0x76 is the BME280 on the same bus.
const BMP388_ADDR: u8 = 0x77;

/// MLX90614 I2C address (factory default; not remapped in EEPROM).
const MLX90614_ADDR: u8 = 0x5A;

/// BME280 I2C address (SDO → GND). 0x77 is the BMP388.
const BME280_ADDR: u8 = 0x76;

/// VEML7700 fixed I2C address (not configurable).
const VEML7700_ADDR: u8 = 0x10;

/// PV-side INA219 address (U6, A0/A1 → GND): solar panel voltage + harvest current.
const INA_PV_ADDR: u8 = 0x40;

/// Battery-side INA219 address (U7, A0 → VS): battery voltage + load current.
const INA_BATT_ADDR: u8 = 0x41;

/// Thin `'static`-spawnable wrapper for the BLE task.
#[embassy_executor::task]
async fn ble_task(controller: ble::Controller) {
    ble::run(controller).await;
}

#[esp_rtos::main]
async fn main(spawner: Spawner) {
    let config = esp_hal::Config::default().with_cpu_clock(CpuClock::max());
    let peripherals = esp_hal::init(config);

    // Heap must be initialised before esp_rtos::start and before BleConnector::new.
    // 72 KiB is sufficient for the trouble-host BLE stack; ESP32-H2 has 320 KiB SRAM.
    esp_alloc::heap_allocator!(size: 72 * 1024);

    info!("Starting ESP32-H2 Weather Station");

    // Start the esp-rtos scheduler: it owns timer group 0 (the embassy time driver)
    // and the FROM_CPU0 software interrupt that drives the thread-mode executor.
    // IMPORTANT (per esp-radio docs): the scheduler must be started BEFORE the radio.
    let timg0 = TimerGroup::new(peripherals.TIMG0);
    let sw_int = SoftwareInterruptControl::new(peripherals.SW_INTERRUPT);
    esp_rtos::start(timg0.timer0, sw_int.software_interrupt0);

    // Flash-backed config: read the NVS partition range from the partition table,
    // then hand the FlashStorage singleton to the config task. The partition-table
    // read only borrows `flash` for the duration of the call; the move into
    // `config::run` happens afterward, so there is no borrow/move conflict.
    let mut flash = FlashStorage::new(peripherals.FLASH);
    let flash_range = {
        // 512 B buffer: 16 × 32-byte entries — ample for any typical table.
        let mut pt_buf = [0_u8; 512];
        let pt = read_partition_table(&mut flash, &mut pt_buf).expect("partition table");
        let nvs = pt
            .find_partition(PartitionType::Data(DataPartitionSubType::Nvs))
            .expect("nvs partition lookup")
            .expect("nvs partition present");
        nvs.offset()..nvs.offset().saturating_add(nvs.len())
    };
    spawner.spawn(config::run(flash, flash_range).expect("config task already spawned"));

    // RWDT supervisor: create the RTC handle and spawn the watchdog task.
    // Rtc::new takes LPWR; the supervisor feeds the RWDT while all tasks beat.
    let rtc = Rtc::new(peripherals.LPWR);
    spawner.spawn(watchdog::supervise(rtc).expect("watchdog already spawned"));

    // BLE: create the HCI connector and wrap it in an ExternalController for trouble-host.
    // BleConnector::new must be called AFTER esp_rtos::start (radio requires the scheduler).
    let connector =
        BleConnector::new(peripherals.BT, BleConfig::default()).expect("BLE controller init");
    let controller: ble::Controller = trouble_host::prelude::ExternalController::new(connector);
    spawner.spawn(ble_task(controller).expect("ble_task already spawned"));

    // BMP388 + MLX90614 + BME280 + VEML7700 on I2C0: SDA = GPIO10 (J3/4), SCL = GPIO11
    // (J3/5). External 4.7 kΩ pull-ups to 3V3 on the bus. The shared async mutex lets
    // each sensor task hold the bus for one transaction at a time.
    let mut i2c = I2c::new(
        peripherals.I2C0,
        I2cConfig::default().with_frequency(Rate::from_khz(100)),
    )
    .expect("I2C0 init")
    .with_sda(peripherals.GPIO10)
    .with_scl(peripherals.GPIO11)
    .into_async();

    // One-shot I2C bus scan at boot: enumerate every device that ACKs so the log
    // shows what is physically wired before the sensor tasks take the bus. Expected
    // today: 0x10 VEML7700, 0x40 INA219 (PV), 0x41 INA219 (batt), 0x5A MLX90614,
    // 0x76 BME280, 0x77 BMP388.
    let found = meteo_lib::i2c_scan::scan(&mut i2c).await;
    info!("I2C scan: {} device(s) responding", found.len());
    for &addr in &found {
        info!("  I2C device @ {=u8:#04x}", addr);
    }

    let bus: &'static Mutex<_, _> = I2C_BUS.init(Mutex::new(i2c));

    // Aggregator owns TELEMETRY; spawn it before the sensor tasks so the channel drains.
    spawner.spawn(aggregator::run().expect("aggregator already spawned"));
    let bmp_i2c: SharedI2c = I2cDevice::new(bus);
    spawner
        .spawn(bmp::read_barometer(bmp_i2c, BMP388_ADDR).expect("read_barometer already spawned"));
    let mlx_i2c: SharedI2c = I2cDevice::new(bus);
    spawner.spawn(mlx::read_sky(mlx_i2c, MLX90614_ADDR).expect("read_sky already spawned"));
    let bme_i2c: SharedI2c = I2cDevice::new(bus);
    spawner.spawn(bme::read_humidity(bme_i2c, BME280_ADDR).expect("read_humidity already spawned"));
    let veml_i2c: SharedI2c = I2cDevice::new(bus);
    spawner.spawn(
        veml::read_luminosity(veml_i2c, VEML7700_ADDR).expect("read_luminosity already spawned"),
    );
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

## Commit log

2025-10-25 Init project
    [Basket_Oct24_1103AM.xls]
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2026-01-31 refactor: restructure into workspace with separate crates
    [nucleo_pins.ods]
2026-02-01 fix: resolve clippy warnings in bmp388 and utils
    [bmp388.rs]
2026-02-01 docs: add pin allocation table and reformat nucleo_pins.csv
    [nucleo_pins.csv]
2026-02-01 feat(ble): add BLE UART debug task with line framing
    Add LineBuffer for UART byte stream framing (14 tests) and a ble_debug
    task that reads from USART2, parses RN4871 responses, and logs them via
    defmt. Enable defmt feature on meteo-lib for firmware builds.
2026-02-01 feat(ble): add RN4871 async driver with command mode support
    Add Uart trait for hardware abstraction, Rn4871 driver struct with
    enter/exit command mode, send_command, and wait_for_reboot methods.
    Add process_line to LineBuffer for single-line extraction. 10 async
    tests using MockUart with tokio runtime.
2026-02-01 refactor(ble): split Response into StatusEvent (public) and Response (internal)
    Separate the RN4871 protocol types by concern:
    - StatusEvent enum (public): unsolicited %...% events that callers care
    about (Reboot, Connect, Disconnect, ConnParam, StreamOpen, Unknown)
    - Response enum (crate-internal): command protocol mechanics (Aok, Err,
    Cmd, End, Data) that only the driver uses
    New files:
    - status_event.rs: StatusEvent enum definition
    - status_parser.rs: parser for %...% event content with 12 tests
    Changed files:
    - response.rs: stripped to 5 internal-only variants
    - parser.rs: handles only command responses, no longer parses %...%
    - format.rs: defmt::Format impl for StatusEvent instea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
    [main.rs]
2026-02-01 refactor(ble): introduce typed Command enum for RN4871 operations
    Replace raw byte slices with a typed Command enum that encodes wire
    format and expected response type for each RN4871 operation.
    New file:
    - command.rs: Command enum (SetName, SetFeatures, GetFirmwareVersion,
    GetDeviceName, DumpConfig) with write_to() and response_type(),
    15 tests covering all variants and edge cases
    Driver changes:
    - Add execute(), query(), query_multiline() public methods taking Command
    - Make send_command, send_query, send_multiline_query private helpers
    - Add Error::CommandTooLong variant for buffer overflow handling
    - Update all driver tests to use typed Command API
    Firmware changes:
    - main.rs uses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
    [main.rs]
2026-02-01 fix(ble): remove incorrect SR,2000 feature setting
    [main.rs]
2026-03-14 feat(ble): integrate GATT service setup and sensor data streaming
2026-03-14 fix(ble): handle CMD> as framed line in send_multiline_query
2026-06-14 fix(ble): defer GATT push until client subscribes; bound command-mode ops
    Entering RN4871 command mode (SHW) the instant a client connects stalled the
    module GATT responses during service discovery, so the central never finished
    discovery and the link dropped on supervision timeout (HCI reason 0x08).
    Gate Phase 2 on a CCCD notify-enable (%WC%) instead of just `connected`, so
    discovery and initial reads complete before we ever enter command mode. Wrap
    each command-mode handshake in a 500ms circuit-breaker so a missing CMD>/AOK/END
    marker can no longer wedge the task indefinitely.
2026-06-14 fix(ble-debug): retry capture on transient connection-establishment errors
    The Gaia controller intermittently fails LE connection establishment
    (HCI 0x3e), surfacing as le-connection-abort-by-local or a D-Bus reply
    timeout in meteo-cli. These are transient and unrelated to the firmware,
    so retry them like "device not advertising" instead of aborting the
    capture. A genuine error (e.g. a missing characteristic) still surfaces
    immediately.
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2026-06-14 feat(tui): wire main.rs terminal lifecycle and event loop
2026-06-14 fix(tui): widen sensor readout column so min/max/avg fit
2026-06-14 fix(tui): cleanly disconnect BLE on quit to avoid stale links
    [main.rs]
2026-06-14 fix(bmp388): sample at 1 Hz via forced mode instead of free-running
    The driver put the BMP388 in normal mode (PWR_CTRL=0x33), which free-runs
    continuous measurements at the default 200 Hz ODR. The 1 s read loop only
    throttled how often we read the latest result -- the sensor kept measuring
    200x per second and burning power for samples we discarded.
    Switch to forced mode: new() leaves the sensor in sleep and reads the
    calibration; each read() triggers exactly one measurement, polls the STATUS
    data-ready flags for completion (no fixed delay), then returns to sleep. The
    existing 1 Hz read loop now drives the sampling cadence -- one measurement per
    second, matching the datasheet's recommended w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
    [bmp388.rs]
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2026-06-14 docs(ble): document BLE module, wire contract, and gaia testing
2026-06-23 fix(tui): scope and bound BLE discovery, tear down on signal
    [main.rs]
2026-06-23 fix(ble): frame RN4871 %events% and CMD> prompt without newline; send R,1 raw
    The RN4871 emits %...% status events (incl. %REBOOT%) with no trailing
    newline and replies to R,1 with %REBOOT% (not AOK), and ships in prompt
    mode (CMD> ). read_line now returns on a complete %...% token or the
    CMD> prompt, classify recognizes the prompt, and provision sends R,1 raw
    and waits for the reboot event. Without this, bring-up hung in reset()
    forever. Adds host tests with the real (newline-free) framing.
2026-06-23 fix(ble): drop-oldest sensor channel so a stalled link cannot freeze sensing
    publish_sample replaces the blocking SENSOR_CHANNEL.send().await in the
    BMP task. When the BLE consumer is slow or wedged and the channel fills,
    the oldest unconsumed sample is dropped instead of back-pressuring the
    sensor task (which previously froze acquisition at 9 readings whenever
    the BLE link stalled). Telemetry is latest-wins.
    [bmp.rs]
2026-06-23 fix(ble): full-time advertising + RN4871 SHW provisioning/supervision
    Primary fix (hard requirement): the device now advertises FULL-TIME while idle.
    The bare `A` command only fast-advertises for 30 s then goes dark, so the station
    became undiscoverable ~30 s after boot/disconnect. `A,<interval>` with a single
    parameter (no total-time) advertises forever (user guide 2.4.x); we use A,00A0
    (160 ms) for both initial and post-disconnect advertising. Verified: discoverable
    after 59 s of uptime, and data streams continuously once connected.
    Also, RN4871 V1.30 protocol/provisioning fixes:
    - classify() matches AOK/ERR case-insensitively (module answers lowercase `Err`;
    was treated as data, loopin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
2026-06-23 fix(ble): reliable telemetry link — advertising keepalive + central connect/resolve/discovery
    The full path (discover → connect → GATT resolve → subscribe → stream) now
    works and self-heals; live Temperature+Pressure verified streaming on gaia.
    Firmware (ble.rs):
    - Re-arm advertising on a periodic idle tick. On RN4871 V1.30, `A,<interval>`
    does NOT advertise forever — it goes silent after a while, leaving the device
    undiscoverable (it was only ever caught right after a boot). Re-issuing `A`
    while idle keeps it continuously discoverable. Never re-arm while connected —
    issuing `A` mid-connection disrupts the notification path.
    Central (meteo-tui/feed.rs):
    - Wait for dis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
2026-06-23 fix(ble): continuous advertising (STA) + faster discovery, GATT-resolution fixes
    Firmware (rn4871.rs, ble.rs):
    - STA,0020,FFFF,0020: advertise connectably at 20 ms CONTINUOUSLY. The RN4871
    default drops from fast (20 ms) to slow (961 ms) advertising after 30 s, which
    made a central race the ~1 s gaps and time out (le-connection-abort-by-local)
    and made discovery hit-or-miss. A large real fast time-out (0 means "advertise
    zero time" on V1.30, NOT "forever") with slow == fast keeps it at 20 ms.
    - SS,00: drop the unused Device Information service so GATT resolution needs
    fewer ATT round-trips on a lossy link.
    - Broaden %DISCONNECT% match to a prefix and drain buffered events after eac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
2026-06-23 feat(ble): RN4871 link driver from datasheet (no GATT)
2026-06-23 feat(ble): firmware BLE supervisor task + USART2/RST_N wiring
2026-06-23 docs(ble): RN4871 pin rows + soak-test procedure (CLAUDE.md, README.md)
2026-06-23 fix(ble): observable self-recovering bring-up (timeout circuit-breaker + step logs)
2026-06-23 fix(ble): enable Device Info + Transparent UART services (SS,C0) so the module accepts connections
2026-06-23 docs(esp32-h2): add ESP32-H2-DevKitM-1 datasheet summary and sensor pin map
2026-06-23 feat(esp32-h2): port firmware from STM32H753 to ESP32-H2
    Replace embassy-stm32/cortex-m/probe-rs stack with esp-hal 1.0 + esp-hal-embassy
    for the ESP32-H2 (riscv32imac). Drop the RN4871 BLE module path (on-chip BLE is a
    later task). Onboard WS2812 RGB on GPIO8 via esp-hal-smartled; BMP388 on I2C0
    (SDA=GPIO10, SCL=GPIO11). defmt over native USB-Serial-JTAG via esp-println.
    [bmp.rs, main.rs]
2026-06-23 chore(cargo): adopt rust-scaffold Cargo.toml recommendations
    - resolver "3"; workspace.package rust-version = 1.85, publish = false
    (inherited by both crates)
    - profiles: release gains codegen-units = 1 (keeps debug = true / no strip so
    defmt symbols survive for espflash decode); add dev / gdb / profiling
    - lints: adopt the rust-scaffold group structure (restriction/pedantic/nursery/
    cargo = warn) + [lints.rust] unsafe_code/unused, with an allow-list tuned for
    this no_std embedded firmware (mod.rs layout, infinite task loops, slice
    indexing, esp dep-tree version dups, fixed-point casts, pre-existing driver
    style). Safety-relevant restriction lints (unwrap/expect/panic/arithmetic/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
2026-06-23 chore(cleanup): remove pre-workspace STM32 leftovers
    Delete the dead root-level files from before the workspace split (not workspace
    members, never compiled): src/{main,lib,bmp388}.rs, build.rs, Cargo.toml.old —
    all referencing the old single-crate meteo_station + embassy-stm32. Fix a stale
    thumbv7em mention in the Justfile clippy-recipe comment.
    [bmp388.rs, main.rs]
2026-06-23 docs(brainstorm): re-ground BLE module design on ESP32-H2 on-chip radio
2026-06-23 docs(plan): add BLE telemetry peripheral implementation plan
    Plan derived from brainstorm 1 for the on-chip ESP32-H2 BLE telemetry
    peripheral (esp-radio 0.18 + trouble-host 0.6): host-tested wire frame in
    meteo-lib, GATT Notify peripheral, RWDT heartbeat supervisor, RN4871 cleanup.
    Central deferred to a follow-up. Passed plan-reviewer round 2 (PASS).
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2026-06-23 feat(ble): telemetry wire frame v1 with host tests
2026-06-23 feat(ble): on-chip BLE stack bring-up — connectable advertising
2026-06-23 feat(ble): GATT telemetry service + 1 Hz notify
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2026-06-23 fix(ble): correct on-device advertising, address, and watchdog liveness
    Three runtime bugs surfaced flashing the firmware on the ESP32-H2 (gaia) that the
    host build/clippy/fmt gate could not catch:
    1. AD overflow panic at boot. Flags + CompleteLocalName("MeteoStation") + 128-bit
    ServiceUuids128 = 35 bytes > the 31-byte legacy advertisement limit, so
    AdStructure::encode_slice returned Err and .expect panicked in a boot loop. Fix:
    move the 128-bit service UUID into the scan-response data; the advertisement
    keeps Flags + name (17 bytes), the scan response carries the UUID (18 bytes).
    2. Static-random address byte order reversed. STATION_ADDR was [0xF0,..,0x01], but
    Address::ran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
2026-06-23 fix(ble): request robust connection parameters on connect
    Soak testing on gaia reproduced the historical link instability (risk #7): the
    link drops with reason "Connection Timeout" at a variable interval (~10 s–200 s)
    while the firmware is provably healthy throughout (sampling, notifying, watchdog
    feeding, no chip reset). btmon root-caused it: the connection is established with a
    supervision timeout of only 420 ms (BlueZ kernel default — gaias
    ConnectionSupervisionTimeout is commented out in main.conf), so any brief RF stall
    exceeding 420 ms drops the link.
    As a peripheral, request RequestedConnParams::default() (80 ms interval, 8 s
    supervision, 0 latency) after each connection via upda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
2026-06-23 fix(ble): negotiate 8 s supervision timeout over L2CAP to stop link drops
    The peripheral requests an 8 s supervision timeout on connect, but the ESP32-H2 controller accepts the HCI LE Connection Update (Command Status = success) without ever running the LL connection-parameters-request procedure on air, so the negotiated parameters never changed: the link stayed at BlueZ's ~420 ms default and dropped on any brief central-radio stall (Connection Timeout, HCI 0x08) at 2-203 s intervals.
    Vendor trouble-host 0.6.0 at ../trouble-host (copied from the crates.io source) with a one-line change in update_connection_params restricting the HCI conn-param path to the central role, so a peripheral falls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
2026-06-23 feat(ble): expose firmware version via Device Information Service
2026-06-23 feat(tui): wire tokio event loop, crossterm input, and CLI
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2026-06-23 feat(frame)!: bump telemetry wire frame to v2 with diagnostics byte
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2026-06-23 build(deps): add embassy-embedded-hal and static-cell for shared I2C bus
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2026-06-23 feat(bus): add shared I2C0 bus module for multi-sensor access
2026-06-23 feat(aggregator): add aggregator task, sensor channel, and AGG_BEAT watchdog gate
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2026-06-23 feat(bmp): send readings on sensor channel with init/read resilience
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2026-06-23 docs: sync README + CLAUDE.md to current state (MLX90614, v2 frame, on-chip BLE, sky-temp chart)
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2026-06-23 docs(power): add KiCad power-subsystem schematic + generator
    [meteo_power.kicad_sch]
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2026-06-23 fix(tui): clamp non-negative chart axes to zero (no negative lux)
2026-06-24 feat(firmware): add hands-free RJ11 live-pair probe binary
    A throwaway bench tool to identify the live conductor pair of a SparkFun
    weather-meter RJ11 cable without a multimeter or extra hands. Jumper cable
    conductors to GPIO0/3/4/5, actuate the sensor, and the live pair prints over
    defmt. A continuous matrix scan drives each candidate pin LOW in turn while
    reading the pulled-up others, so a closed reed (anemometer, rain gauge) or a
    low-resistance vane position identifies the pair regardless of conductor order.
    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
2026-06-24 feat(weather-meter): add wind speed/direction + rain-rate telemetry (frame v3)
    Wires the SparkFun SEN-15901 weather meter end to end:
    - meteo-lib: weather_meter module (anemometer Hz->m/s, wind-vane ADC mV->heading
    via the 3.3 V divider table, sliding-window rain-rate mm/h estimator),
    host-tested; SensorReading::{WindSpeed,WindDir,Rain} aggregator variants.
    - BLE frame bumped to v3 (20 bytes): rain rate at bytes 17-18 (deci-mm/h),
    diagnostics moved to byte 19; encode/decode + tests updated.
    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
2026-06-24 fix(bme): log BME280 absence once, not every retry
    The BME280 task warned on every 1 Hz init/read failure, spamming the log when
    the sensor is absent (the bench part is usually a mis-ordered BMP280, which never
    ACKs at 0x76). Edge-gate the logging: one WARN on the transition to faulted, one
    INFO on recovery. Retries still run silently every cycle so a real BME280
    self-heals if plugged in, and the BME280_FAULT diagnostic bit stays set.
    [bme.rs]
2026-06-25 fix(veml): publish luminosity at 1 Hz, not the integration-time rate
    The VEML7700 task looped at the sensor integration time (~100 ms), so it sent
    and logged luminosity ~10×/s while every other sensor reports at 1 Hz. Pace the
    loop with a 1 Hz Ticker; sample() still does its integration-time settle and
    auto-range discard logic, the Ticker just bounds how often it runs. MLX90614 is
    left at its deliberate 2 s datasheet-recommended cadence.
    [veml.rs]
2026-06-25 feat(power): add dual INA219 current/power monitoring
    Two INA219 breakouts (INA219B, on-board 0.1ohm shunt, +/-3.2A) on the shared
    I2C0 bus replace the GPIO2 analog battery divider:
    - U6 @ 0x40: high-side on the PV feed (SOLAR+ -> SOLAR_CHG) -> solar harvest
    current + panel voltage.
    - U7 @ 0x41: high-side on the battery->boost feed (VBAT -> VLOAD) -> system
    load current + battery voltage (INA219 bus register, more accurate than the
    H2 SAR ADC).
    R1/R2 + the VSENSE net are dropped; the DevKit connector shrinks 6->5 pins and
    GPIO2/ADC1_CH1 is freed as a spare. C1 bulk moves to VLOAD (boost VIN, after the
    U7 shunt). Generated via gen_power_sch.py; ERC clean (0 violations).
    Also gitignor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
    [meteo_power.kicad_sch]
2026-06-25 fix(power): correct BMP388 address and add BME280/VEML7700 to the sheet
    The power sheet's I2C section was stale: U4 was labelled 0x76 (that's the BME280's
    address) and the BME280 + VEML7700 the firmware actually drives weren't shown at all.
    - U4 BMP388: 0x76 -> 0x77 (matches the firmware / CLAUDE.md).
    - Add U8 BME280 (0x76) and U9 VEML7700 (0x10) to the shared I2C0 bus.
    Both new parts are breakout modules with onboard decoupling, so no external 100nF is
    added (noted on the sheet); only the bare MLX90614 keeps its discrete cap. Regenerated
    via gen_power_sch.py; ERC clean (0 violations).
    [meteo_power.kicad_sch]
2026-06-25 feat(lib): INA219 driver, frame v4 power fields, battery SoC curve
    Add INA219 current/bus-voltage driver (host-tested conversions) for the two
    power monitors (PV @0x40, battery @0x41), grow the BLE wire frame to v4 (28
    bytes): append solar_mv/solar_ma/batt_mv/load_ma (u16 LE, u16::MAX sentinel)
    and assign diagnostics bits 6/7 to the INA PV/battery faults. Add a 1S-LiPo
    voltage→SoC curve (battery_pct_from_mv) feeding battery_pct, and the
    SolarPower/BatteryPower SensorReading variants + aggregator handling.
2026-06-25 feat(firmware): read both INA219 power monitors over I2C0
    Add a per-rail INA219 task (spawned twice: PV @0x40, battery @0x41) that
    publishes SolarPower/BatteryPower readings at 1 Hz and degrades to a fault
    reading (blanking V/I, raising the INA diagnostics bit) on init/read failure —
    non-gating, like the BME280/VEML7700 tasks. Bump the sensor channel capacity
    to 16 for the now-9 producers. The v4 28-byte notify needs no MTU code: the
    DefaultPacketPool MTU (251) yields a 247-byte default ATT MTU, which a central
    negotiates via ATT ExchangeMtu before subscribing to CCCD.
    [ina.rs, ina219.rs, main.rs]
2026-06-25 feat(tui): power readouts + wind & humidity charts
    Decode and display the v4 power fields: a Solar row (panel V/I + derived W),
    a Battery row (voltage + derived %), and a Load row (load current + derived W),
    plus the two INA219 fault labels in the diagnostics line. Add scrolling
    wind-speed and humidity charts (six charts total). Update ble_notify_check.sh
    to expect 28-byte frames with byte[0] == 0x04, and refresh CLAUDE.md for the
    v4 frame, the INA219 driver/task, and the battery-curve module.
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2026-06-26 fix(tui): make gradient fill opt-in (--fill); readable traces by default
    [main.rs]
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2026-06-26 fix(tui): clearer gust overlay, pressure off cyan, rename load plot to « Puissance utilisée »
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2026-06-26 fix(tui): adaptive power unit (mW/W) in summary Solaire/Charge headlines
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2026-06-26 fix(meteo-lib): satisfy inline_trait_bounds clippy lint in i2c_scan
    [i2c_scan.rs]
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2026-06-27 fix(meteo-web): make the dashboard work in the browser (hydration, layout, live state, charts)
    Found during manual acceptance (the automated compile/clippy/unit-test gate
    cannot catch runtime or visual breakage). Four root causes:
    - WASM hydration panic 'time not implemented on this platform': chrono was
    pulled with default-features=false, dropping the wasmbind feature, so the
    client-side Utc::now() calls fell through to std::time and aborted hydration
    (dead nav, no live data). Enable chrono's wasmbind feature.
    - CSS class drift: style/main.scss (written before the components) targeted a
    guessed class vocabulary; the components emit different names, so the compass
    overlay, grid, a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
    [chart.rs]
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
